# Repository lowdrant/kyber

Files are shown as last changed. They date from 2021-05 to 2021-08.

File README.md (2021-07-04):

# kyber
The toy lightsaber I always wanted as a kid.

## Status
* KyberBoard Rev 1 sent out for fabrication.
* Found Luke Skywalker lightsaber CAD for 3D printing by [CaseStudyno8](https://www.thingiverse.com/thing:1263192/files).
* Circuit design complete and subcircuit interfaces frozen.
* Subcircuits passed breadboard feasibility tests.
* First pass on firmware architecture complete.

## Goals
- Build a lightsaber that extends/retracts, lights up, and makes sound
- Demonstrate "full-stack" electronics engineering skills + some mechanical design
- Stay sane for the rest of the pandemic (everyone needs a hobby)
- Maybe have a Luke Skywalker costume by Halloween 2021?

## [fw](fw/)
Written for the [STM32L051K8T6](hw/KyberBoard/symbol-datasheets/stm32l051t8.pdf) microcontroller. Code should work on any STM32 micrcontroller, and most interfaces are abstracted into header files.

TODO: state diagram

### Configuring STM32CubeIde
Edit project settings to include the multi-project libraries and make the compiler optimize for size. TODO: change saber-libs to holocron-libs
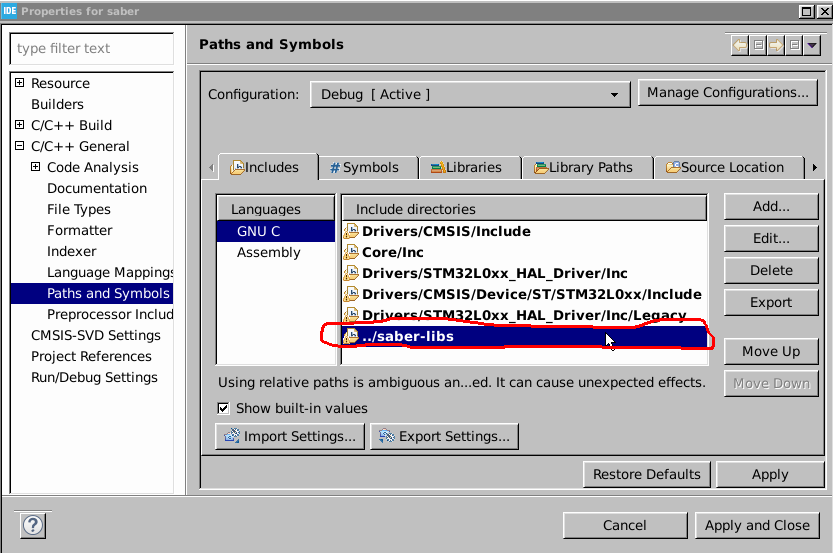
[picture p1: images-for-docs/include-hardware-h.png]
In C/C++ General Settings, add '../saber-libs' to the compiler search path

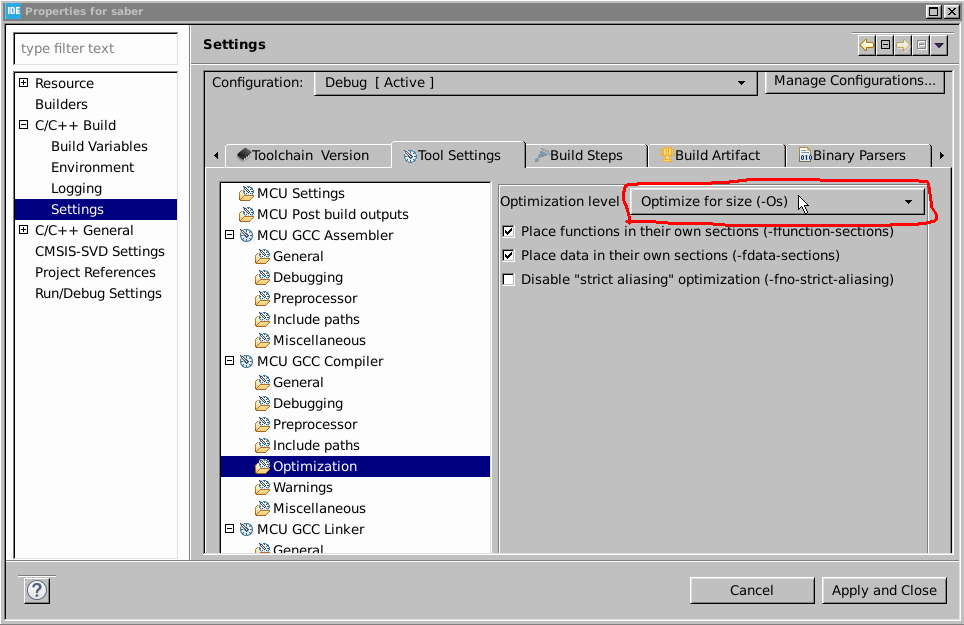
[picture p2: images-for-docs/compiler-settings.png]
Configure the compiler to optimize for size


## [hw](hw/)
A mildly overdesigned PCB to allow flexibility in mechanical design. Designed for test, assembly, and reconfigurability.

### Component Selection Rules
Keep It Simple, Stupid. Stick to driving circuits that have readily available and easily solderable components. If necessary, target components that have in-stock evaluation boards and take the scrap.

### Current (A) Budget
|Component  |Amperage  |Reasoning |
|---|---|---|
|motor |10A |stall current of on-hand dc motor|
|solenoid |1A |12 V/13 Ohms rounded up |
|3V3 bus |1A |typical LDO rating |
|waste |0.5A |safety factor |
|-----------|----------|---------------------------------|
|total |12.5A | |

### Voltage Loss Budget
Mostly concerned with battery protection I<sup>2</sup>R losses. Target < 0.5V peak drop (instinctive spec, not computed)

Major concerns are
- falling below the solenoid turn-on voltage, although I haven't _really_ settled on a solenoid
- throwing off motor control

Current resolution: use ST's [VNHD7008AY eval board example design](reference-manuals/en-vnhd7008ay.pdf). It seems to work fairly well

### Subcircuits
#### Reverse Polarity Protection
Use the built-in protection of the hbridge. Need to characterise I<sup>2</sup>R losses. This will help prevent the Big Dumb<sup>TM</sup> since I plan to use terminal blocks for my main connector.
#### Low-Voltage Shutoff
Grocery store batteries can't drive the actuators, so I'm looking at using a LiPo. This simple Zener-NMOS-PMOS circuit I designed for a student club will should prevent battery over-discharge.
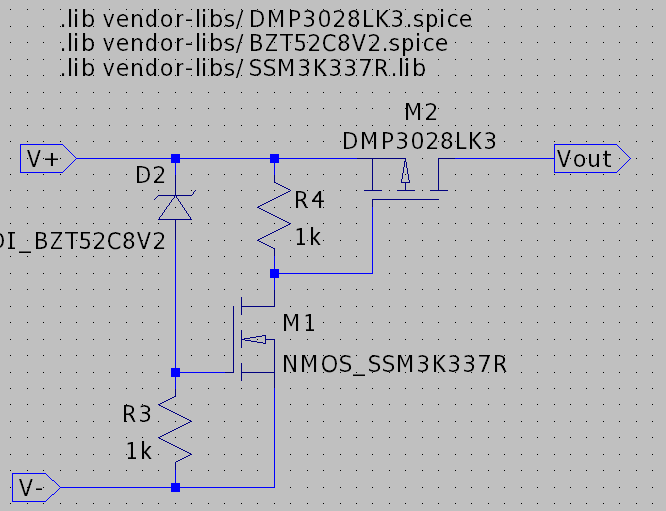
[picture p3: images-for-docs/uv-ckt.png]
UV Protection Circuit

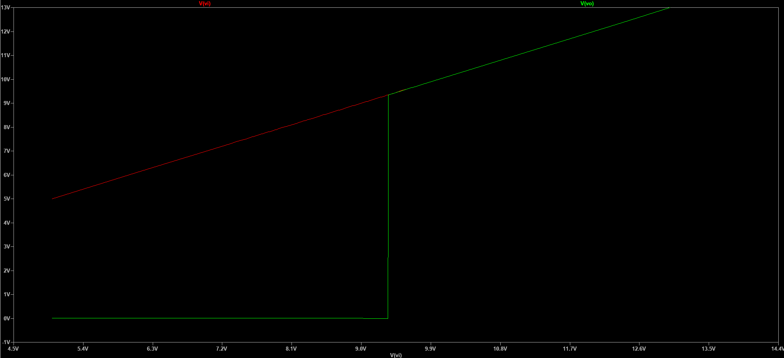
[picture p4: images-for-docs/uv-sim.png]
UV Protection Sim result

When the voltage is above Vthresh, the Zener conducts, so the NMOS conducts, which makes the PMOS conduct.
#### 3V3 Bus
LDO; I do not want to deal with buck converters. I am not being paid for this design.
#### Accelerometer/Gyro
For that sweet, sweet _zwoom_. Use I2C/SPI to make routing a little easier. I have a still-in-stock breakout board for the no-longer-produced [MMA84252QT](https://www.digikey.com/catalog/en/partgroup/mma8452q/11242).
#### Motor Current Sensing
I may use torque control to retract the saber. Currently planning to extend it with a spring, so the "retracted torque" is theoretically better characterized than the "retracted position".
#### HBridge
I found a high-current hbridge IC that does not require complementary PWM (thank you ST). I have limited PWM capabilities due to only low-power ST micros being in stock.
#### Actuators
Low-side switches that do not require inrush-limiting resistors to reduce component count. The [SSM3K337R,LF](https://www.digikey.com/en/products/detail/toshiba-semiconductor-and-storage/SSM3K337R-LF/5056502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) stays well under the maximum drive current and well-preserves a 20kHz square wave.
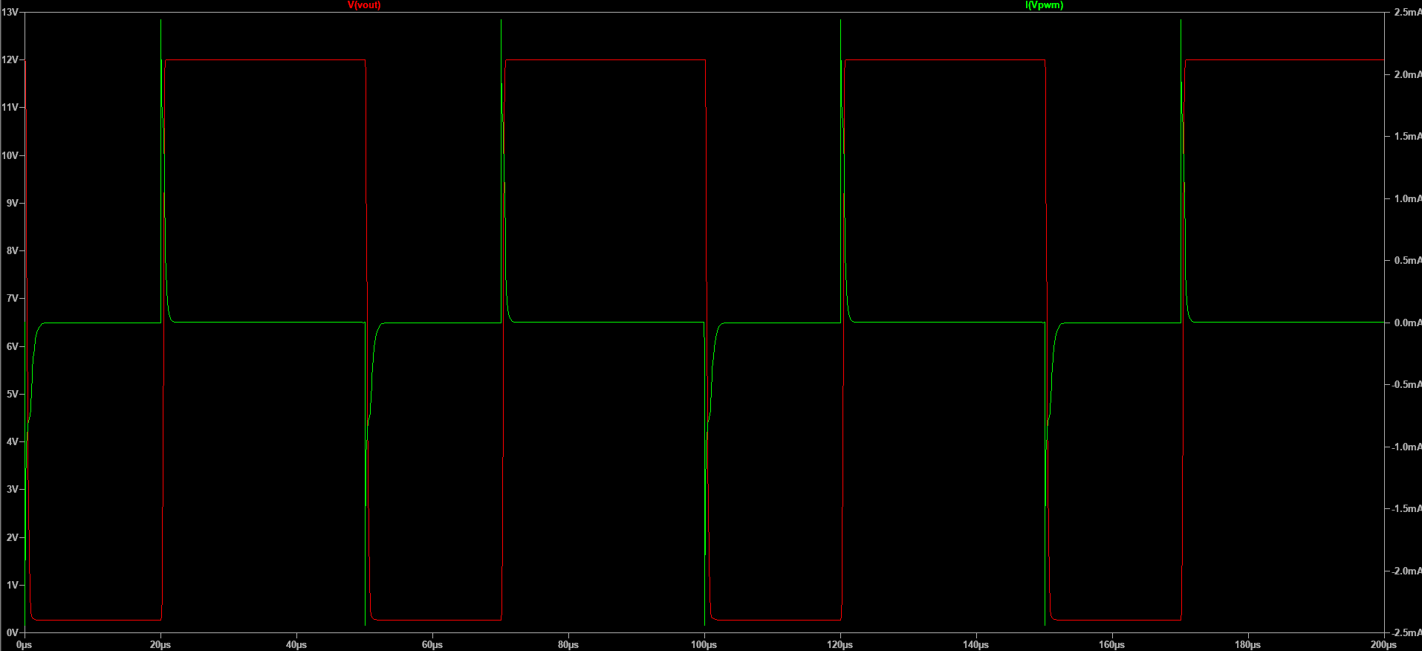
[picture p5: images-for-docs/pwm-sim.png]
PWM Simulation Result


### Non-electrical considerations
- Cost: 4 layers. 2-sided board gives me the needed density, and routing isn't that awful
- I'm not sure I want to hand-solder QFN packages
- Size: Maximize density to maximize mechanical design flexibility.
- Power budget: Meh, I can increase resistances after fab if it's a battery killer

## [cad](cad/)
Found a Luke Skywalker lightsaber CAD for 3D printing by [CaseStudyno8](https://www.thingiverse.com/thing:1263192/files). Was also pointed to Disney's [new lightsaber](https://mashable.com/article/real-lightsaber-star-wars-hotel-disney-world/), which shows some novel mechanical design for retraction. Although I would prefer to be able to fence with my design, the tape measure strategy does show promise.

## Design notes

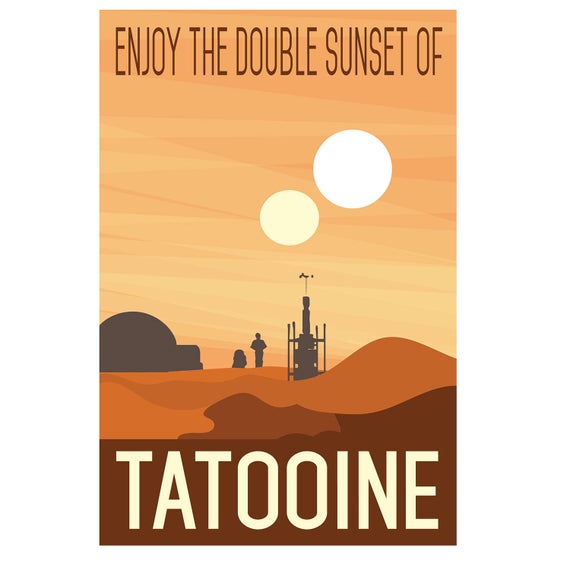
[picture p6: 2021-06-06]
hw/KyberBoard/easter-eggs/tatooine-travel-poster.jpg

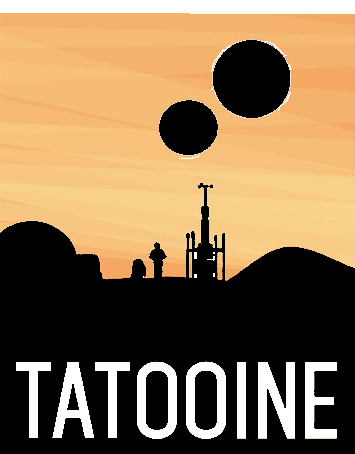
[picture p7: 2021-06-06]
hw/KyberBoard/easter-eggs/tatooine-travel-poster.png

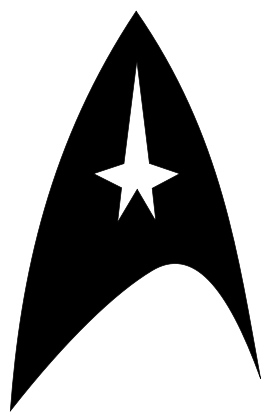
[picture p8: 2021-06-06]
hw/KyberBoard/easter-eggs/starfleet.png

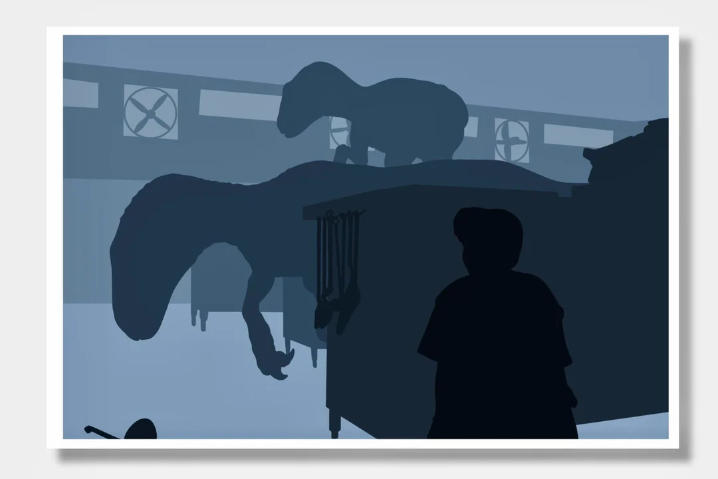
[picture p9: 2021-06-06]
hw/KyberBoard/easter-eggs/velociraptor.webp

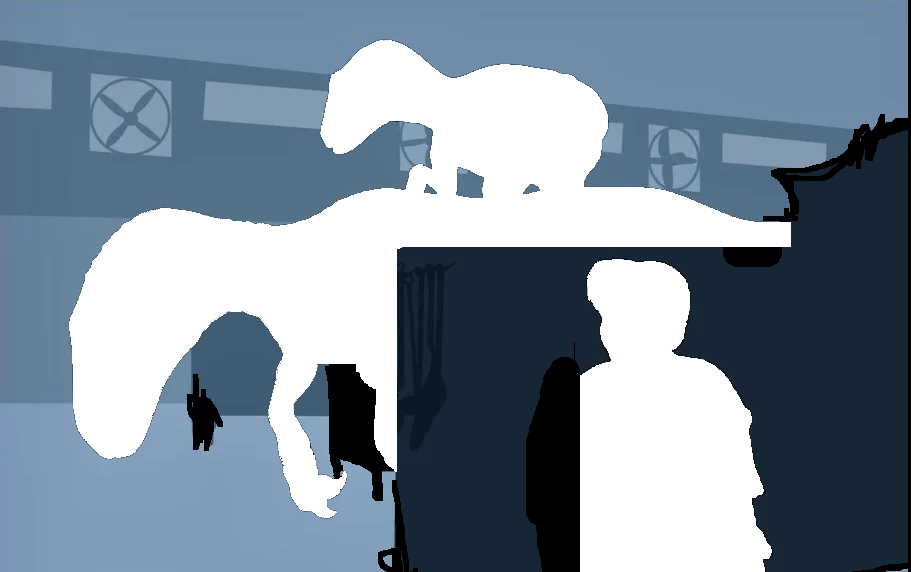
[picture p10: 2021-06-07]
hw/KyberBoard/easter-eggs/velociraptor.png

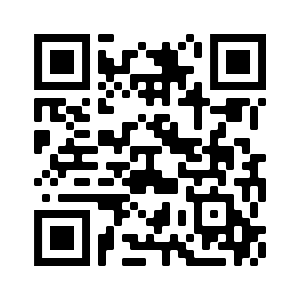
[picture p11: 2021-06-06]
hw/KyberBoard/easter-eggs/qr-funeral-pyre.png

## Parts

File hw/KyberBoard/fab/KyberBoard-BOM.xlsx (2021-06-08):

Id | Designator | Package | Quantity | Designation | Supplier and ref
1 | U4 | MMA8452Q | 1 | MMA8452QT
2 | C15,C2,C4,C5,C7,C8,C17,C18 | C_0603_1608Metric_Pad1.05x0.95mm_HandSolder | 8 | CC0603KRX7R7BB104
7 | Q1 | STL120N4F6AG | 1 | STL120N4F6AG
9 | C6 | CP_Elec_8x10.5 | 1 | UWT1E331MNL1GS
10 | Q4 | STL76DN4LF7AG | 1 | STL76DN4LF7AG
11 | U3 | SOT-223-3_TabPin2 | 1 | AZ1117IH-3.3TRG1
12 | R8,R4,R12,R13,R18 | R_0603_1608Metric_Pad1.05x0.95mm_HandSolder | 5 | CRCW060310K0JNTA
13 | C1 | C_0603_1608Metric_Pad1.05x0.95mm_HandSolder | 1 | CC0603KRX7R7BB333
14 | C3,C12 | C_0603_1608Metric_Pad1.05x0.95mm_HandSolder | 2 | GRM188R61E106KA73D
15 | C9,C11,C10 | C_0603_1608Metric_Pad1.05x0.95mm_HandSolder | 3 | RM188R72A103KA01J
16 | C13 | C_0603_1608Metric_Pad1.05x0.95mm_HandSolder | 1 | GRM188R60J226MEA0J
17 | C16 | C_0603_1608Metric_Pad1.05x0.95mm_HandSolder | 1 | CC0603ZRY5V6BB475
18 | L1 | C_0805_2012Metric | 1 | CIGT201210UHR47MNE
19 | Q3,Q5,Q6,Q7 | SOT-23 | 4 | SSM3K337R
20 | R1,R2,R3,R10,R6,R19,R20 | R_0603_1608Metric_Pad1.05x0.95mm_HandSolder | 7 | CRCW06031K00JNTA
21 | R5 | R_0603_1608Metric_Pad1.05x0.95mm_HandSolder | 1 | CRCW06031K50JNTA
22 | R11,R9 | R_0603_1608Metric_Pad1.05x0.95mm_HandSolder | 2 | CRCW06030000Z0EBC
23 | U2 | ST_PowerSSO-36_SlugDown_ThermalVias | 1 | VNHD7008AYTR
24 | D2 | D_SOD-323_HandSoldering | 1 | BZT52C8V2S-7-F
25 | Q2 | Vishay_PowerPAK_1212-8_Single | 1 | SIS413DN-T1-GE3
26 | 12,3.3,12,3.3 | R_0402_1005Metric | 4 | RC1005J000CS
27 | D4,D5,D6,D7,D8,D9,D12 | D_0603_1608Metric_Pad1.05x0.95mm_HandSolder | 7 | SDM2U30CSP-7
28 |  | TerminalBlock_Phoenix_MPT-0,5-12-2.54_1x12_P2.54mm_Horizontal | 1 | OSTVN12A150
29 | HBT | LED_0603_1608Metric_Pad1.05x0.95mm_HandSolder | 1 | 150060VS75020
30 | UVL | LED_0603_1608Metric_Pad1.05x0.95mm_HandSolder | 1 | 150060RS75020
31 | 12C,3V3 | LED_0603_1608Metric_Pad1.05x0.95mm_HandSolder | 2 | 150060AS75000
33 | , | TerminalBlock_TE_282834-2_1x02_P2.54mm_Horizontal | 2 | 282834-2
34 |  | PinHeader_2x03_P2.54mm_Vertical_SMD | 1 | 15910060
35 |  | SW_SPST_TL3342 | 1 | TL3342F160QG/TR
36 | C19 | C_0603_1608Metric_Pad1.05x0.95mm_HandSolder | 1 | CC0603KRX7R7BB105
37 | U1 | LQFP-32_7x7mm_P0.8mm | 1 | STM32L051K8T6
38 | D13,D14,D15 | D_SOD-523 | 3 | BZT585B3V6T-7

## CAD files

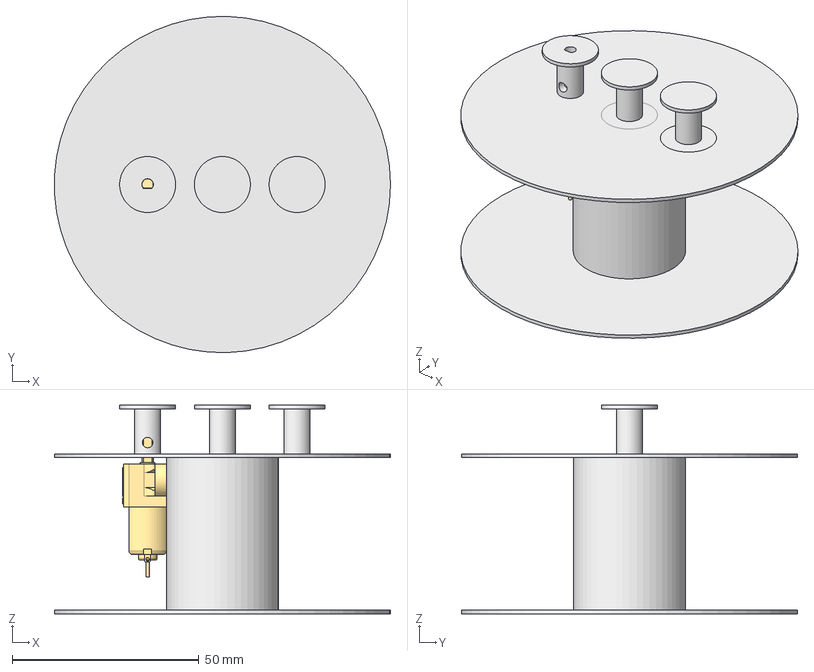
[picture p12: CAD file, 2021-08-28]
cad/innards/assembly.FCStd
89.9 x 90.0 x 55.8 mm
winch-motor
mmgm(extended)_with_bracket
winch-blade1
winch-blade2

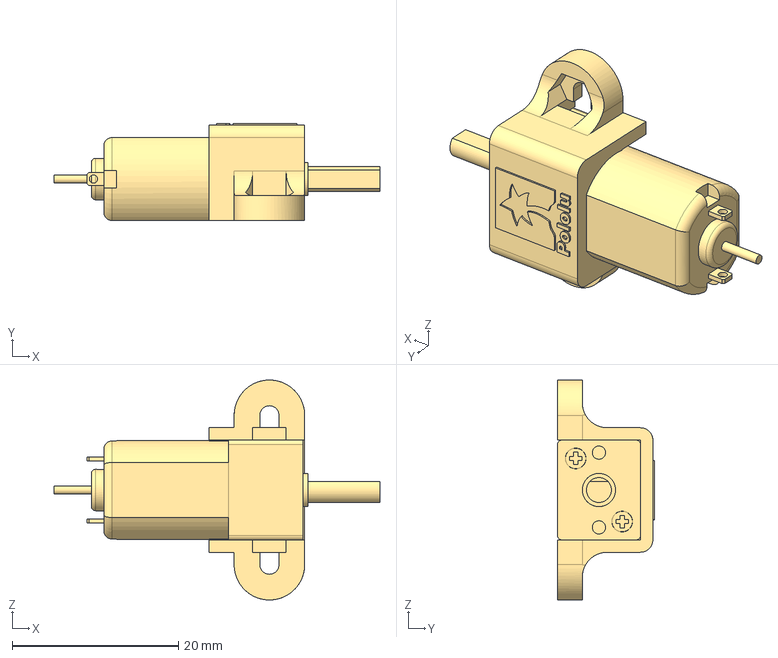
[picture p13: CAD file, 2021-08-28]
cad/innards/motor.FCStd
39.3 x 11.7 x 26.5 mm

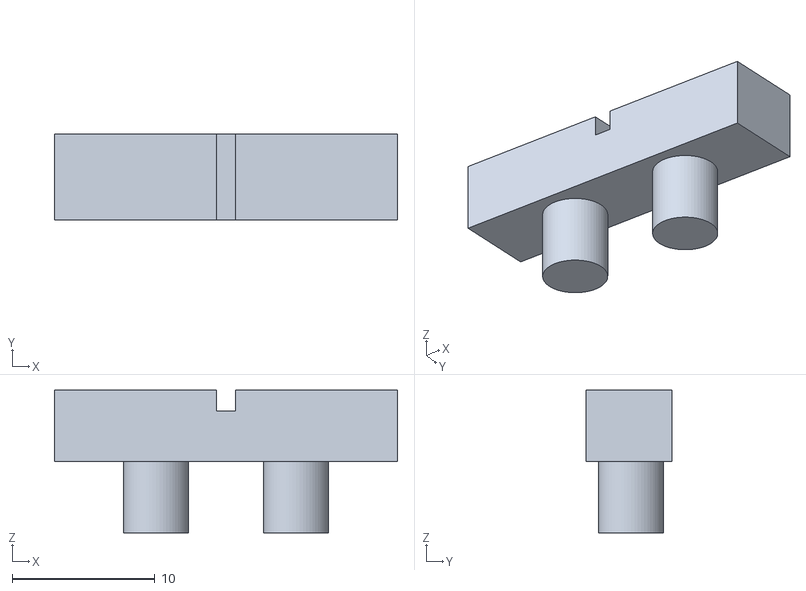
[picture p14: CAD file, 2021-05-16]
cad/saber-base/files/Luke_Skywalker_EP6_-_Power_Regulator.STL
24.0 x 6.00 x 10.0

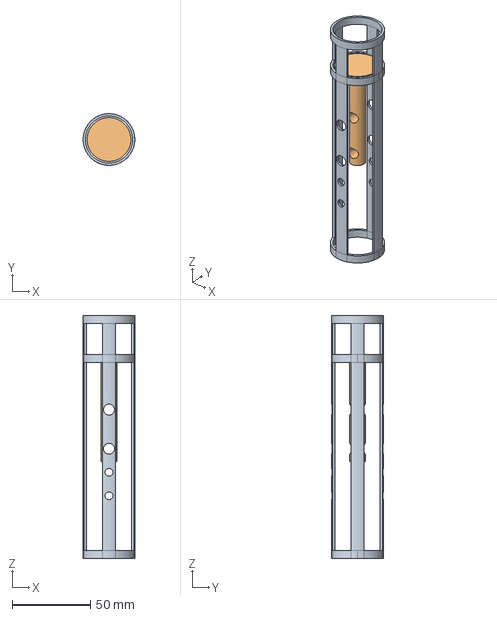
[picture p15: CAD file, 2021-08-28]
cad/test_rig.FCStd
33.0 x 33.0 x 155.0 mm
chassis
shaper

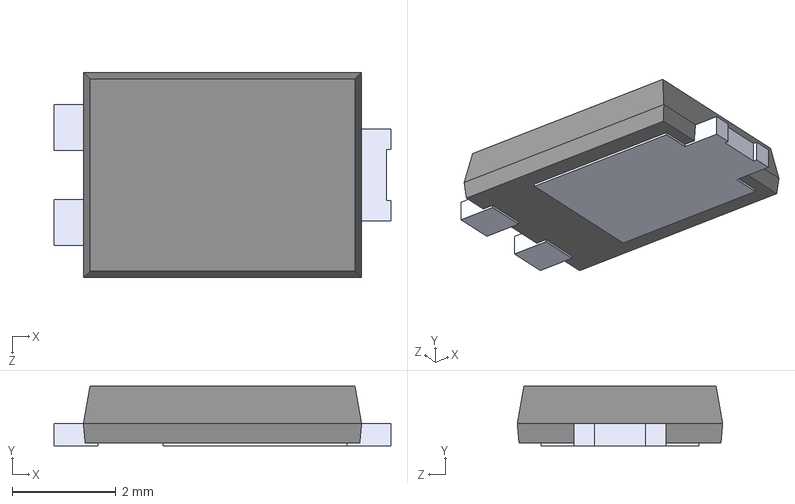
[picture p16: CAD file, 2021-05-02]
hw/KyberBoard/footprints/powerdi5/D_PowerDI5-AAK.step
6.50 x 1.15 x 3.97 mm

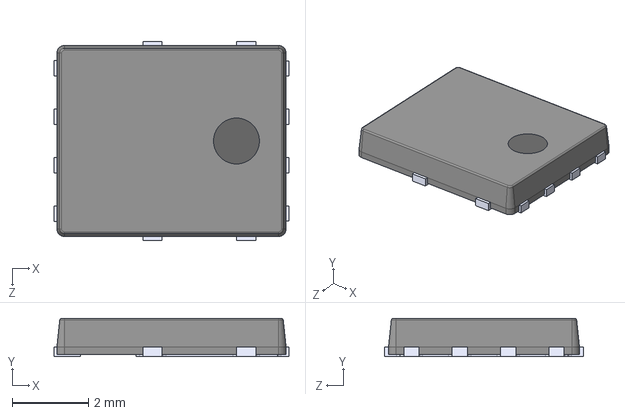
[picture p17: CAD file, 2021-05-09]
hw/KyberBoard/footprints/STL120N4F6AG/STL120N4F6AG.step
6.15 x 1.00 x 5.20 mm

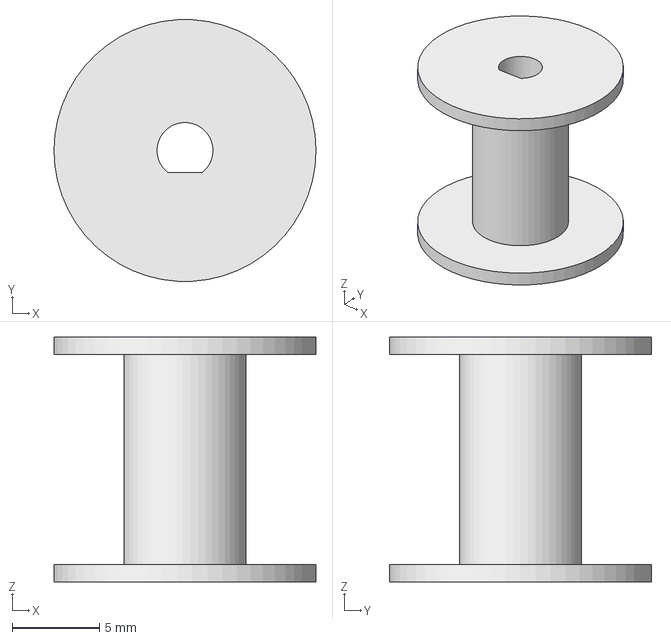
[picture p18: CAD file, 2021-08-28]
cad/innards/winch.FCStd
15.0 x 15.0 x 14.0 mm

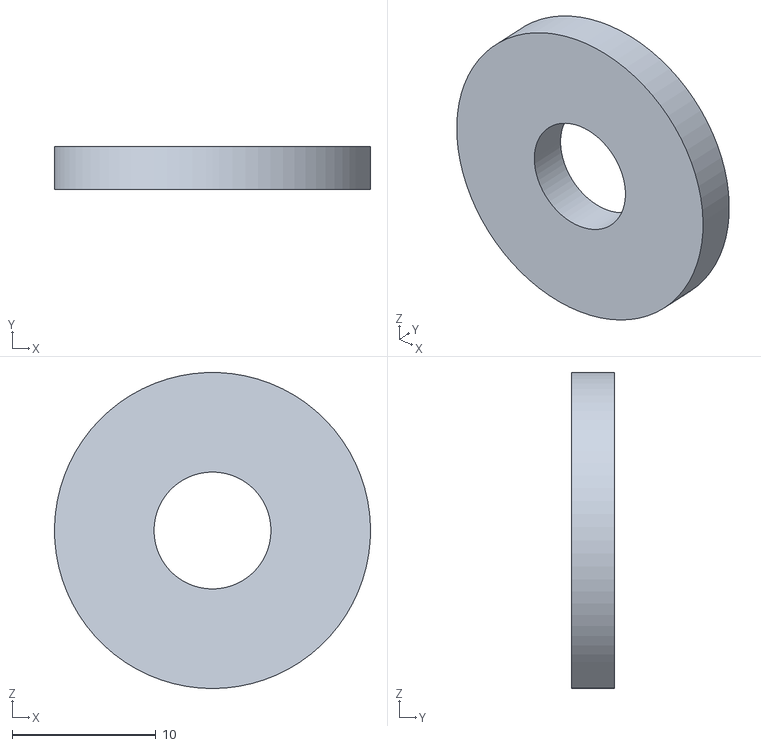
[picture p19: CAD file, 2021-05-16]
cad/saber-base/files/Luke_Skywalker_EP6_-_Lower_Disc.STL
22.0 x 3.00 x 22.0

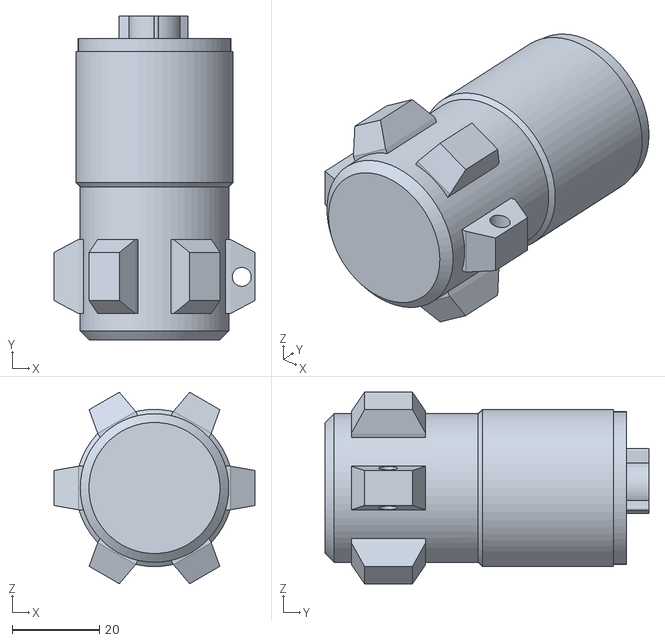
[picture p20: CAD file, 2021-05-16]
cad/saber-base/files/EP6_Luke_Pommel_Solid.STL
46.0 x 74.1 x 43.8

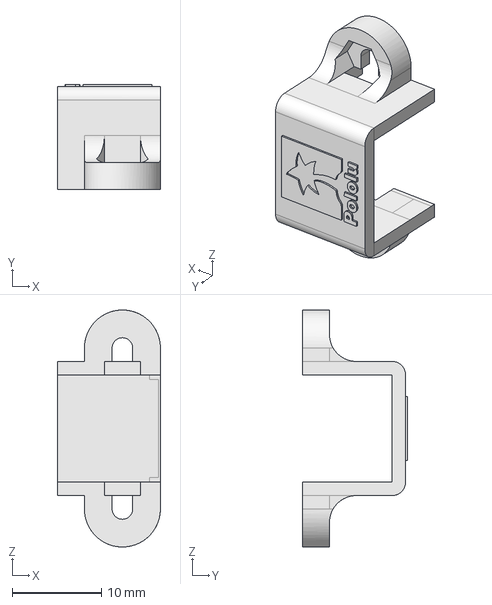
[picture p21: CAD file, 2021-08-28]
cad/innards/MTRBRACKTEST.FCStd
11.5 x 11.7 x 26.5 mm

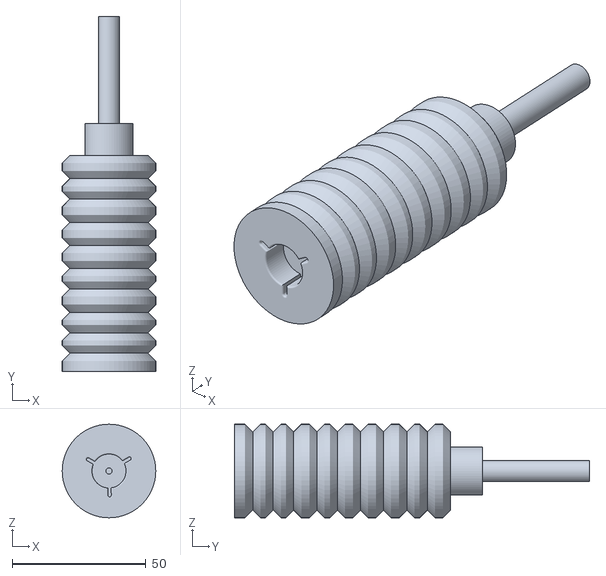
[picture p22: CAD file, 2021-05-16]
cad/saber-base/files/EP6_Luke_Grip_Solid.STL
35.0 x 132.7 x 35.0

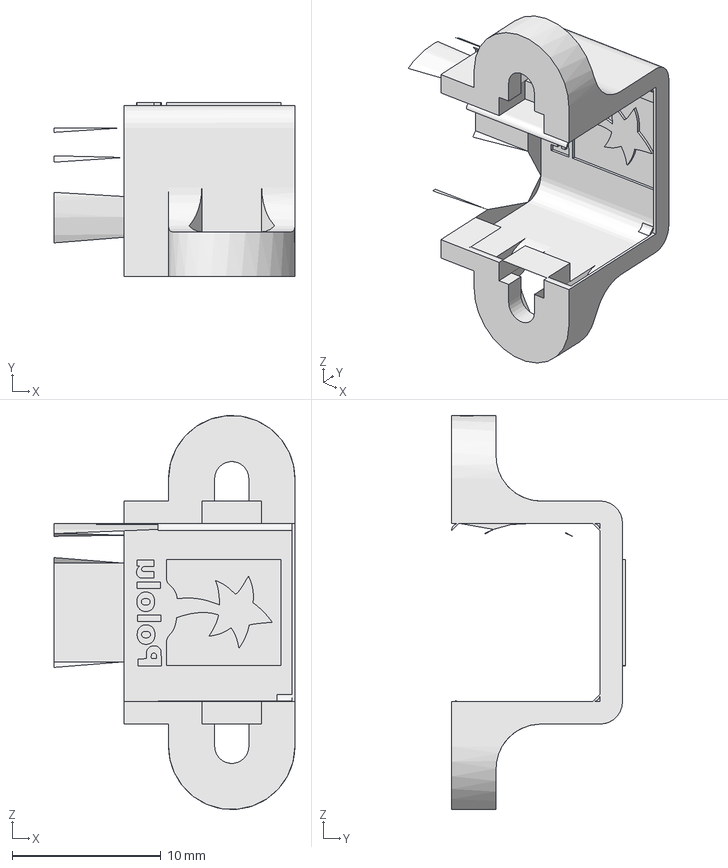
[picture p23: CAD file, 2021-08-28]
cad/innards/motor-bracket.FCStd
16.2 x 11.7 x 26.5 mm

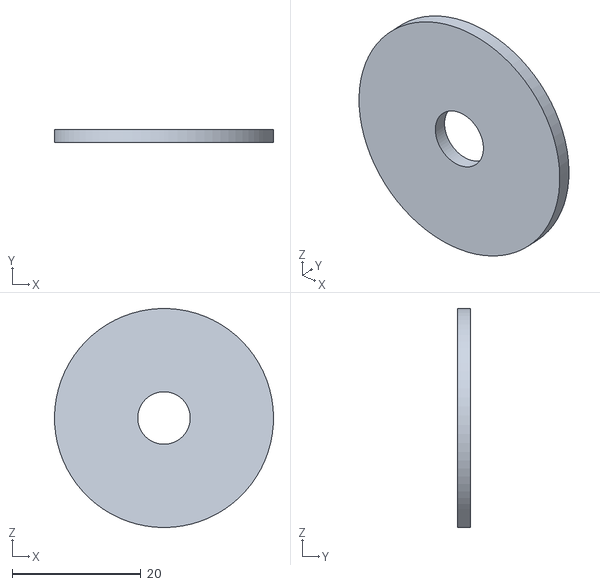
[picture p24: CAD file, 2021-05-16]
cad/saber-base/files/Luke_Skywalker_EP6_-_Upper_Disc.STL
34.0 x 2.00 x 34.0

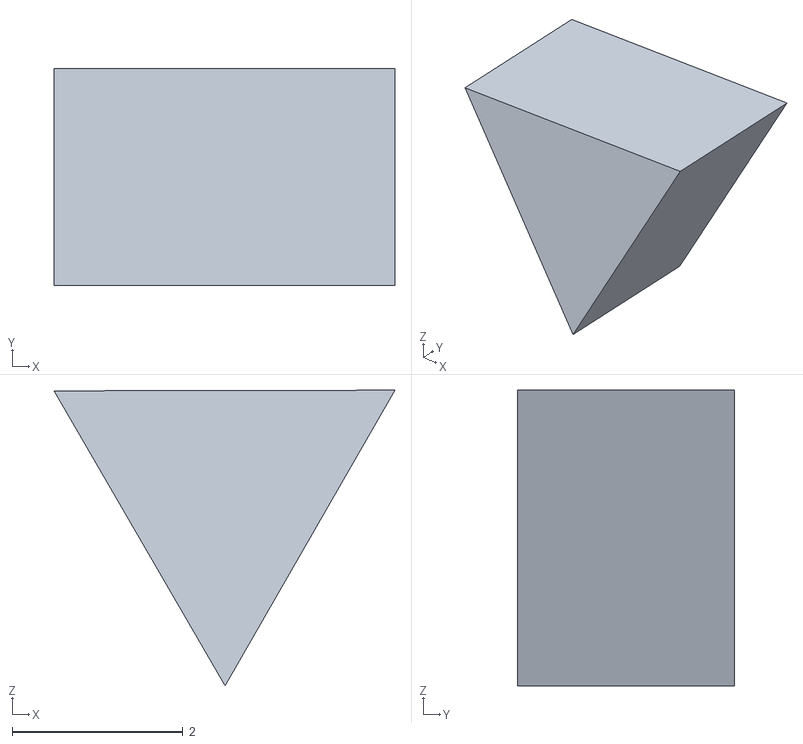
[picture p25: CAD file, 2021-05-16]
cad/saber-base/files/Luke_Skywalker_EP6_-Triangular__Indicator.STL
4.00 x 2.54 x 3.47

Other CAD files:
cad/saber-base/files/Luke_Skywalker_EP6_-_Upper_Copper_Coupling.STL
cad/saber-base/files/EP6_Luke_Midsection_Solid.STL
cad/saber-base/files/Luke_Skywalker_EP6_-_Belt_Ring.STL
cad/saber-base/files/Luke_Skywalker_EP6_-_Emitter_Nipple.STL
cad/saber-base/files/Luke_Skywalker_EP6_-_Grip.STL
cad/saber-base/files/Luke_Skywalker_EP6_-_Luke_Emitter.STL
cad/saber-base/files/Luke_Skywalker_EP6_-_Midsection.STL
cad/saber-base/files/Luke_Skywalker_EP6_-_Pommel.STL
cad/saber-base/files/Luke_Skywalker_EP6_-_Switch.STL
cad/saber-base/files/Luke_Skywalker_EP6_-_Switch_Casing.STL
cad/saber-base/files/Luke_Skywalker_EP6_-__Switch_Lower.STL

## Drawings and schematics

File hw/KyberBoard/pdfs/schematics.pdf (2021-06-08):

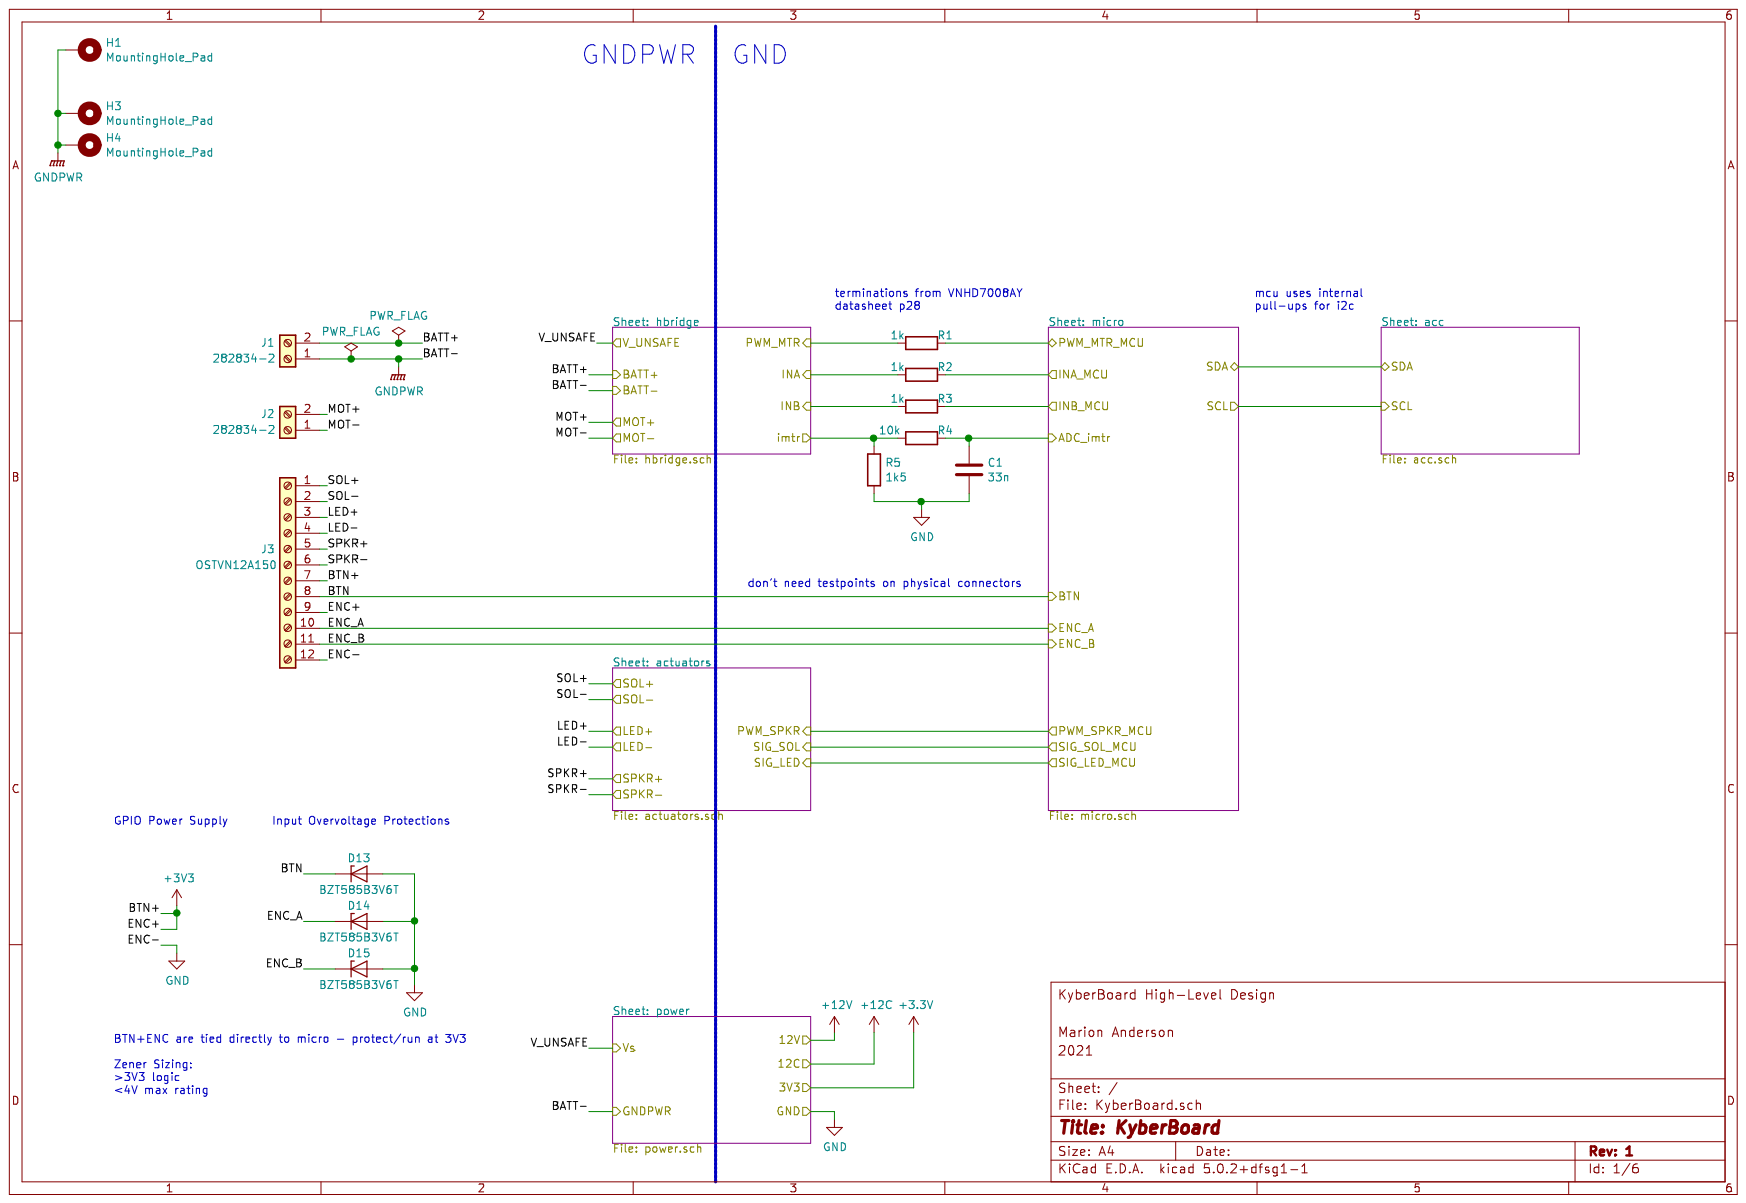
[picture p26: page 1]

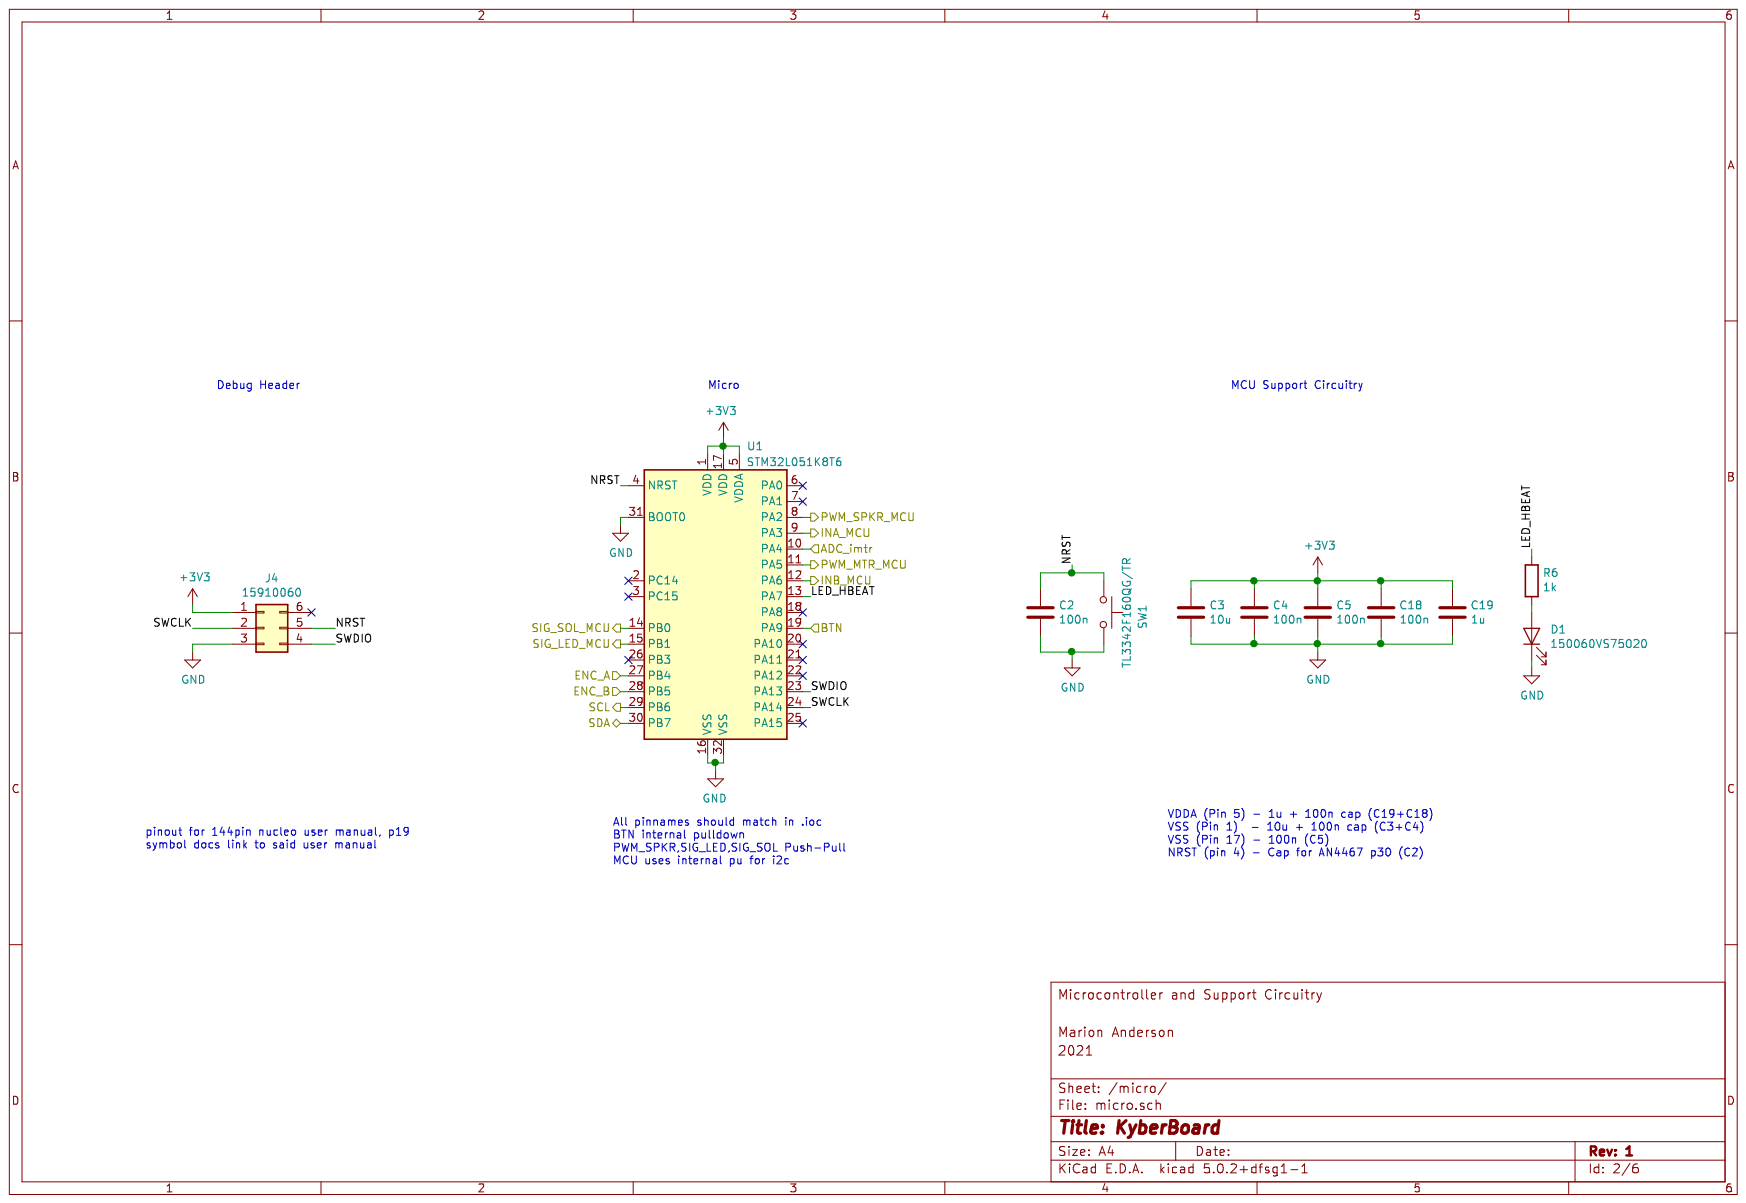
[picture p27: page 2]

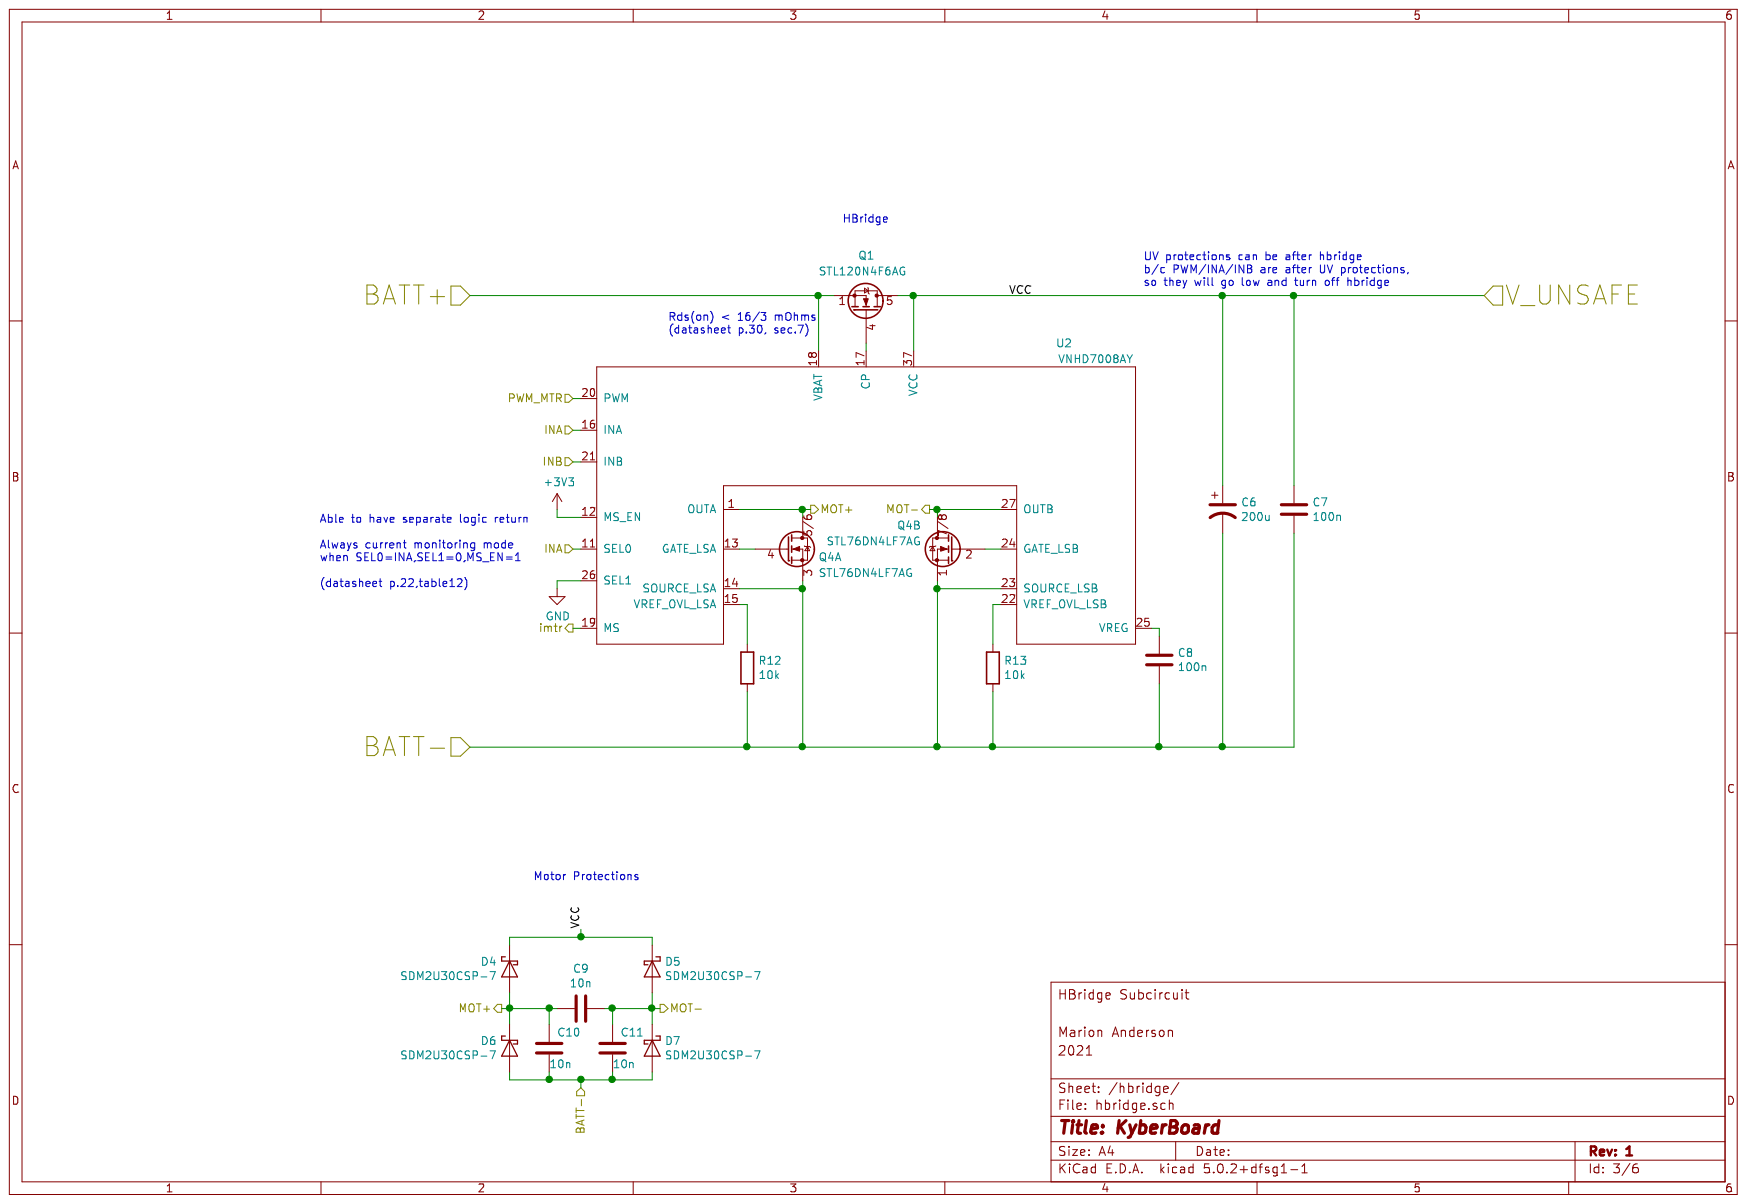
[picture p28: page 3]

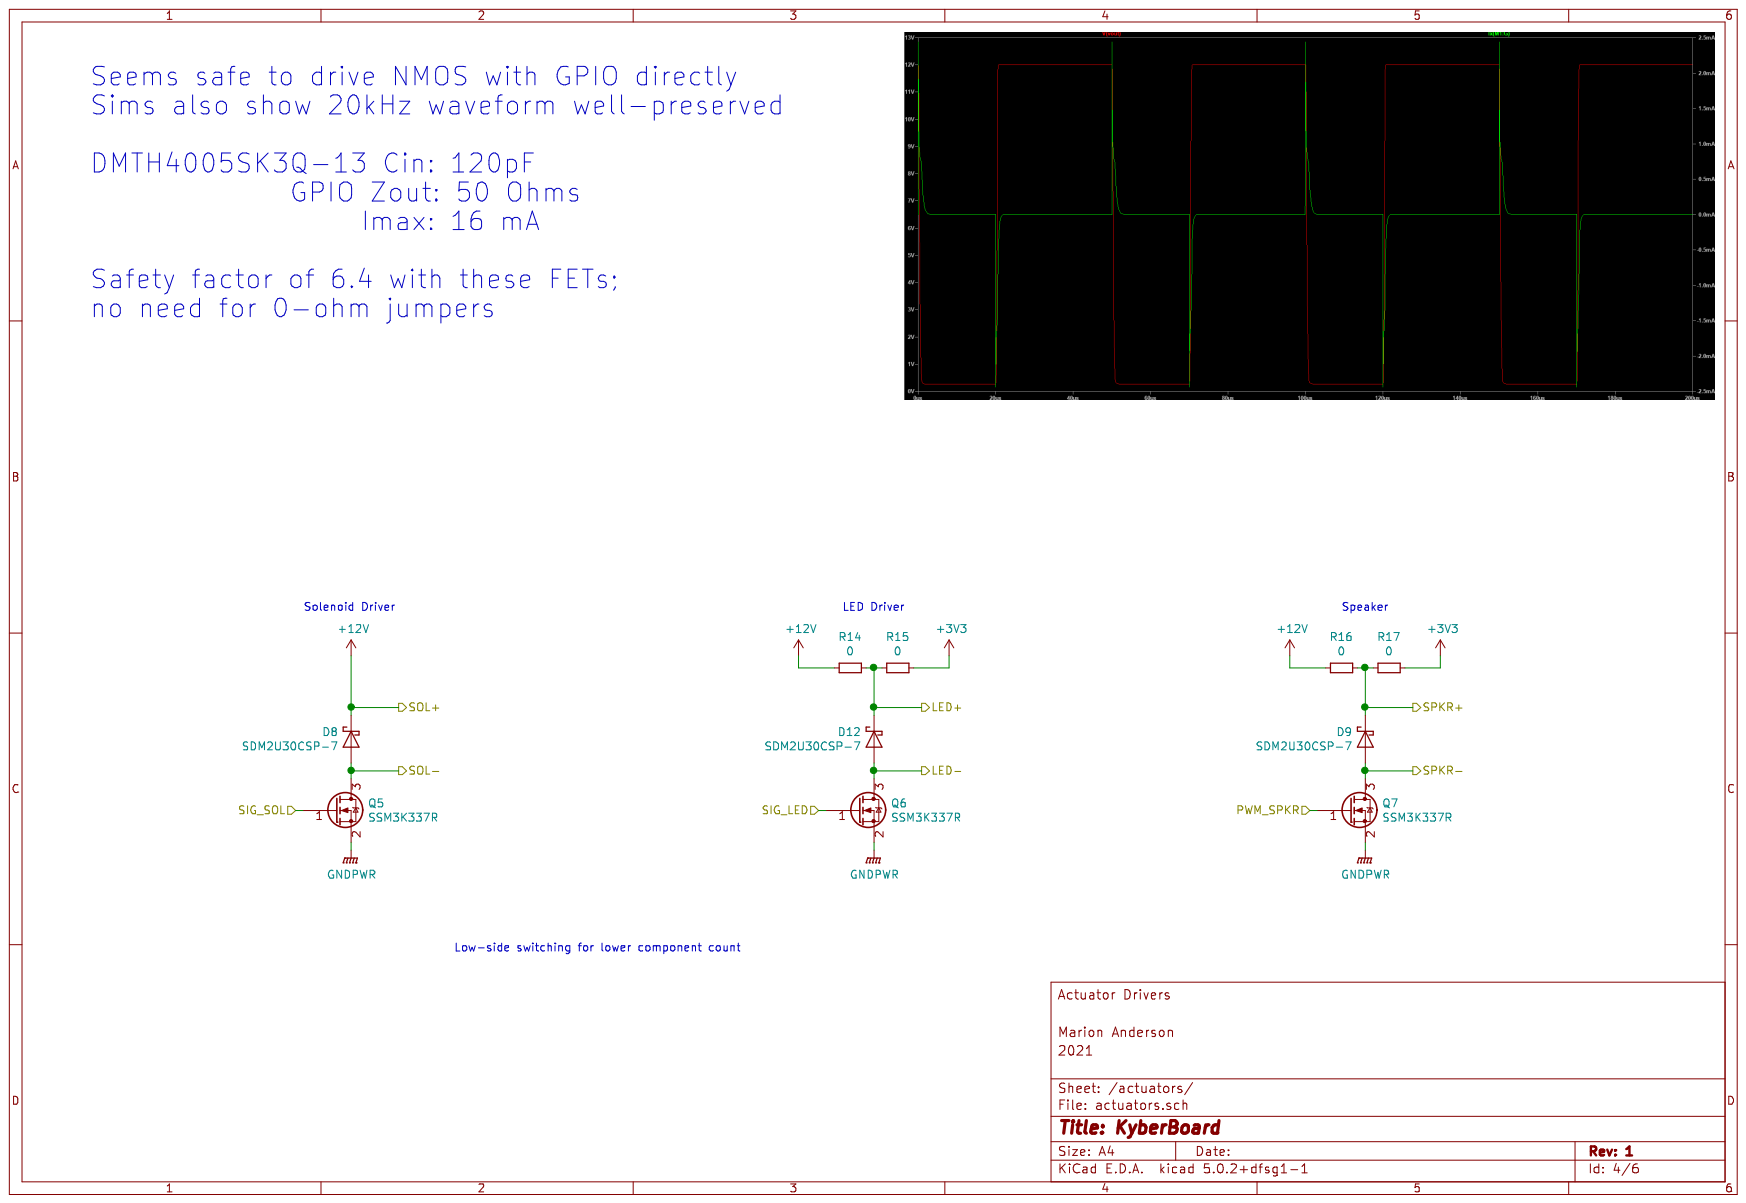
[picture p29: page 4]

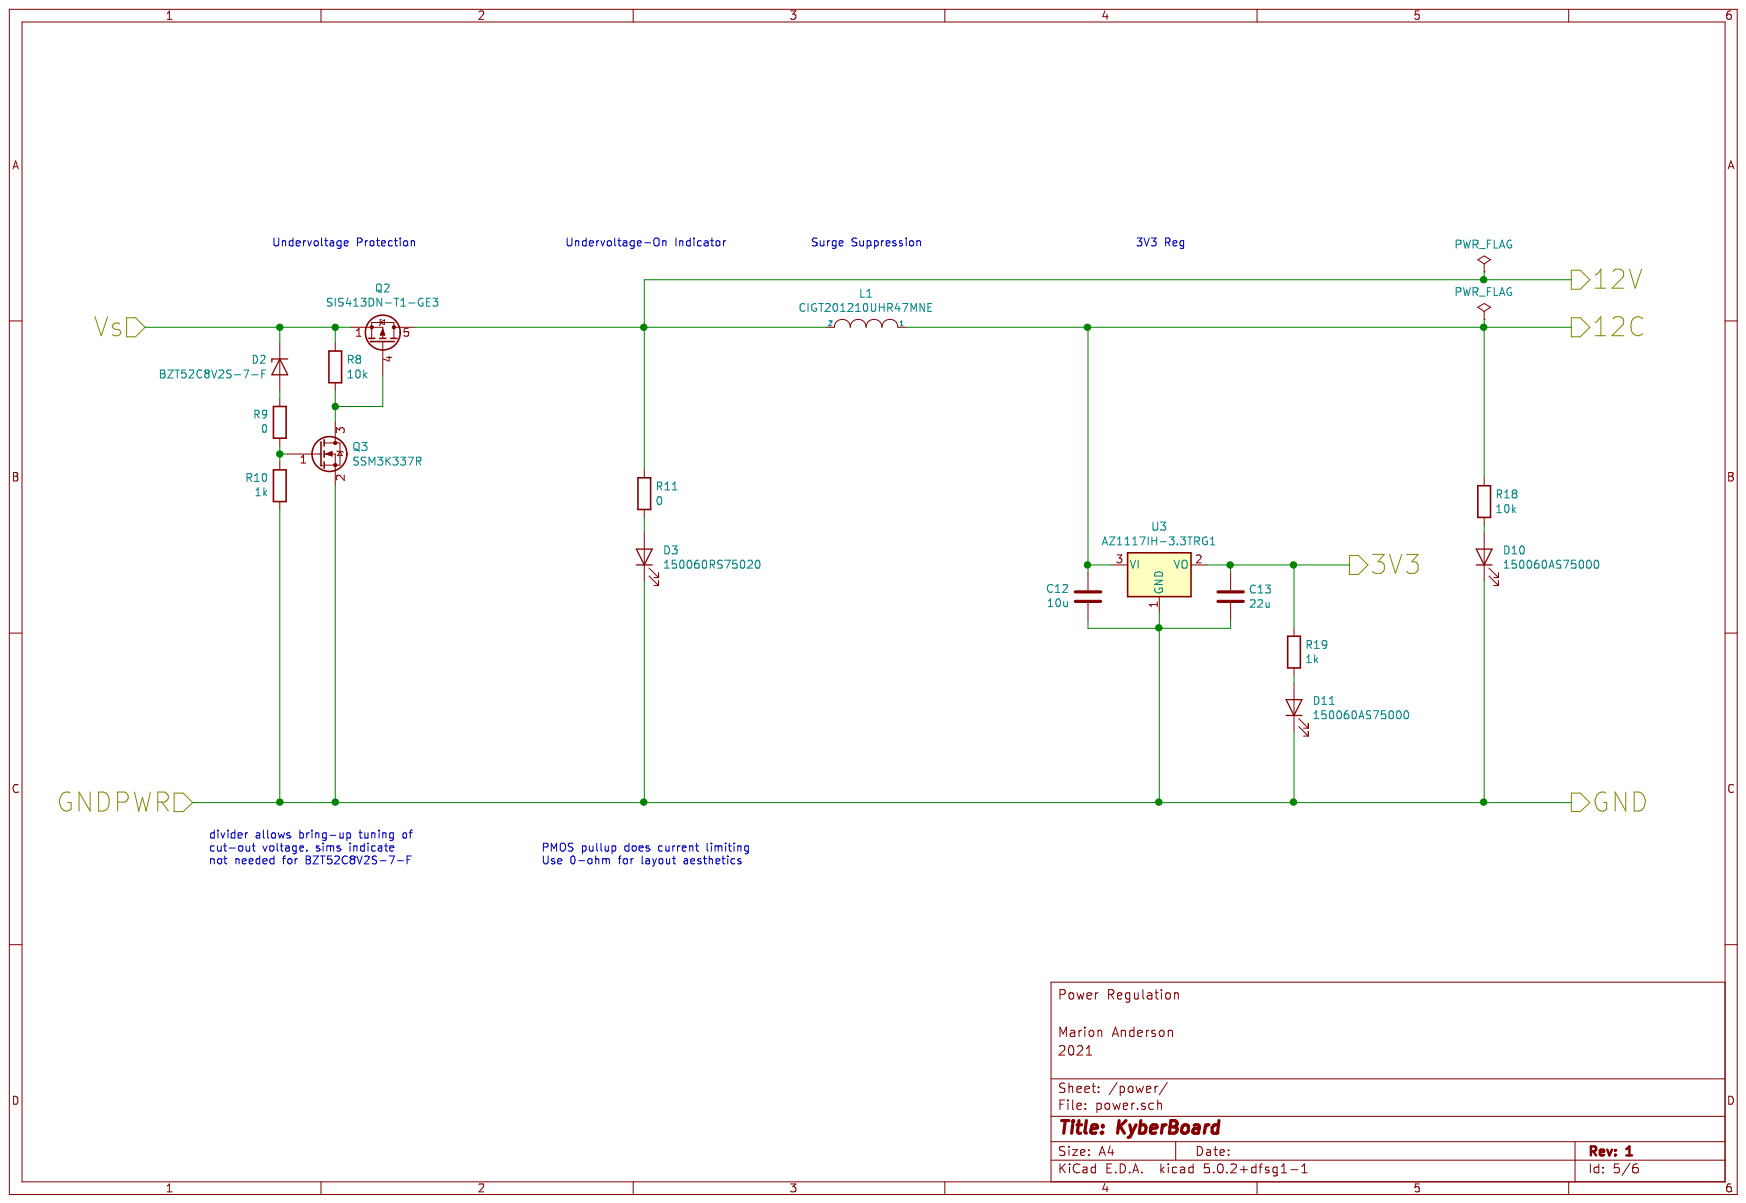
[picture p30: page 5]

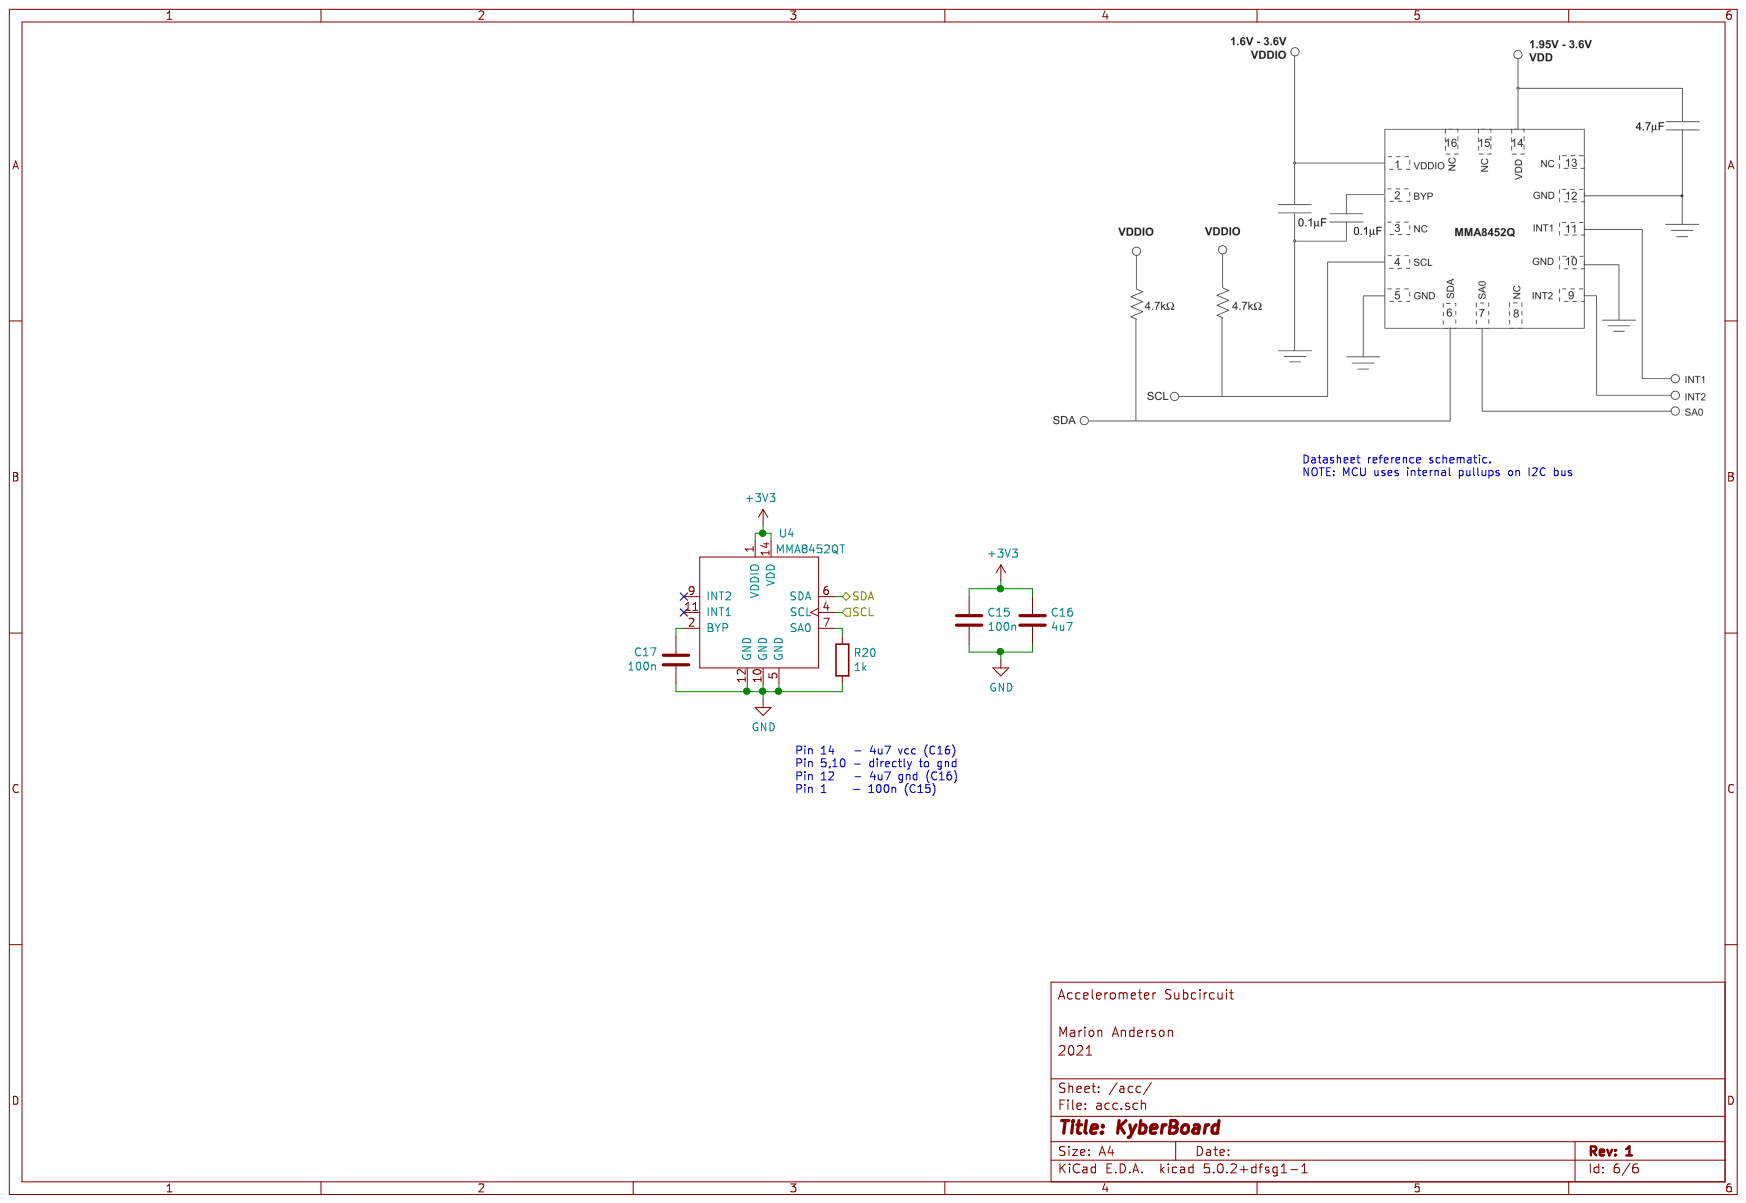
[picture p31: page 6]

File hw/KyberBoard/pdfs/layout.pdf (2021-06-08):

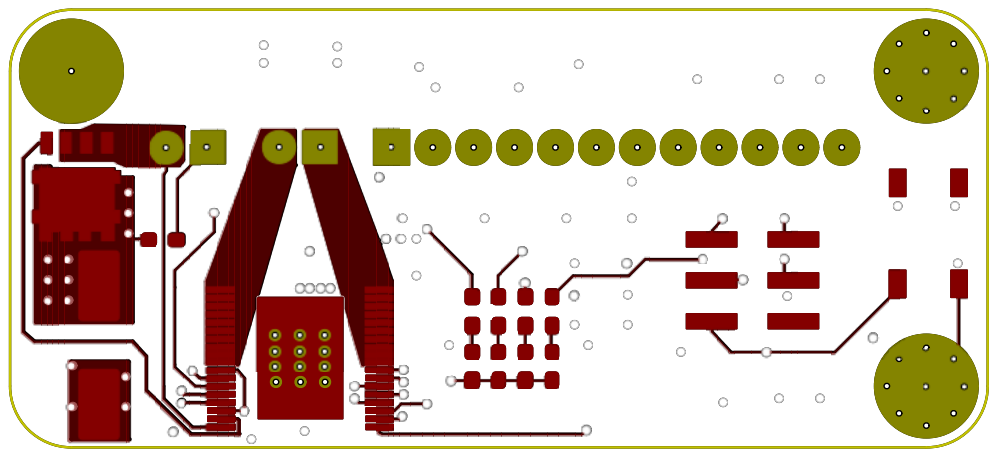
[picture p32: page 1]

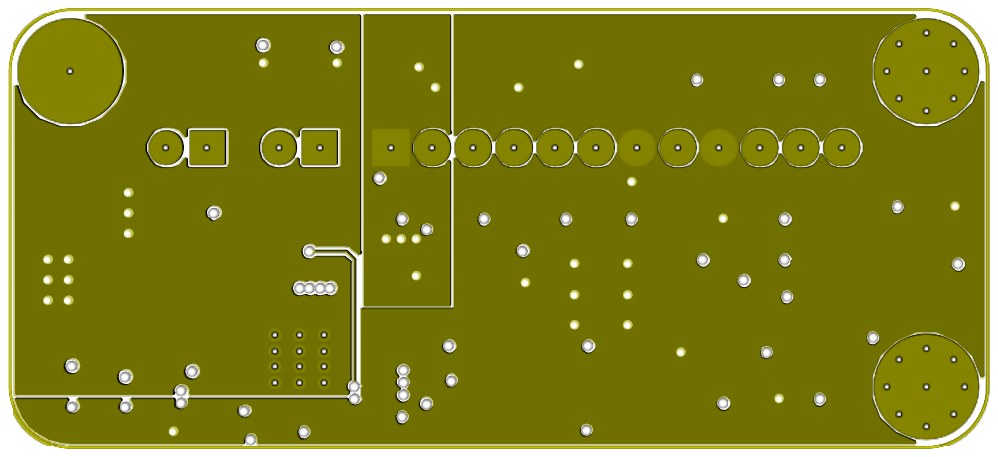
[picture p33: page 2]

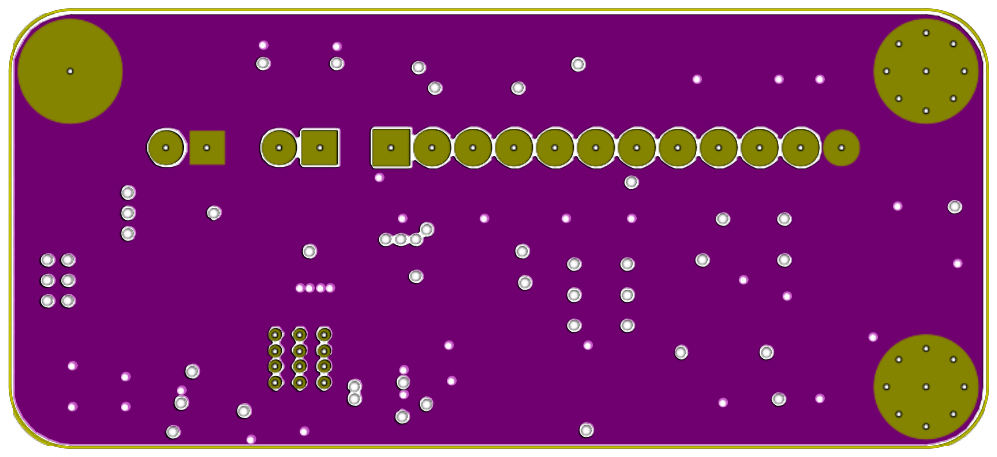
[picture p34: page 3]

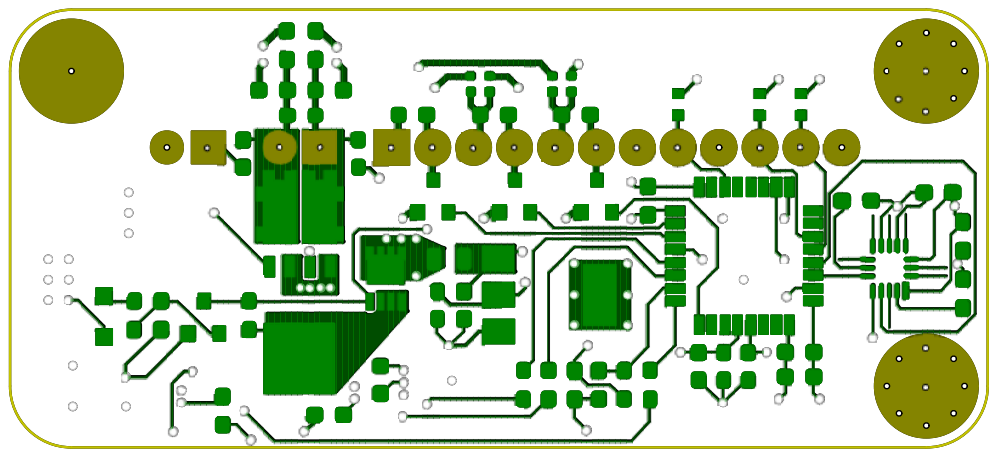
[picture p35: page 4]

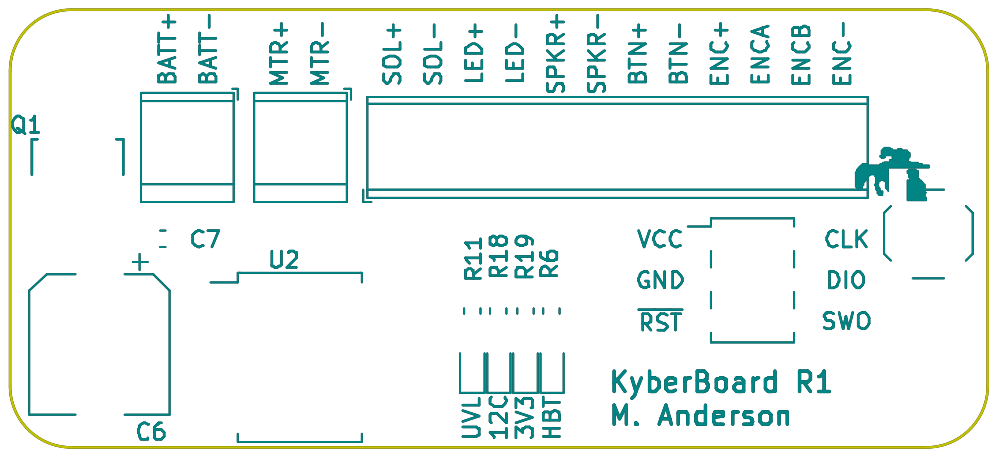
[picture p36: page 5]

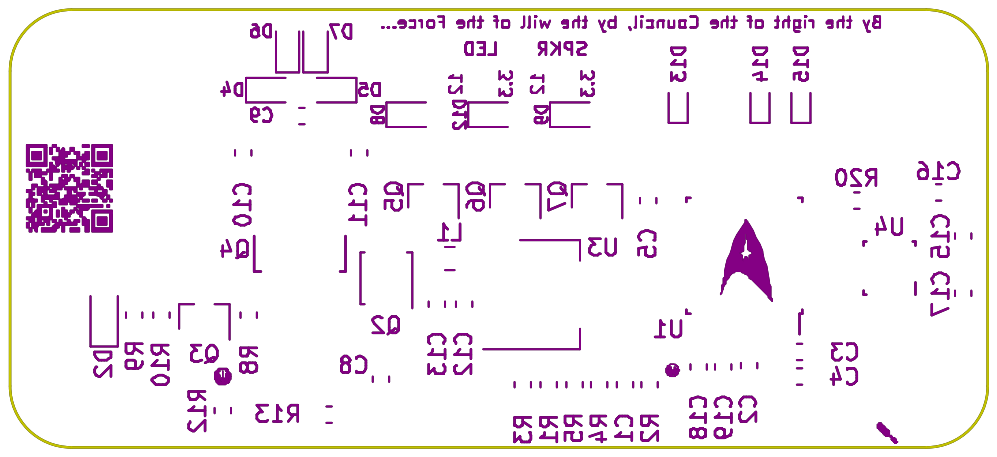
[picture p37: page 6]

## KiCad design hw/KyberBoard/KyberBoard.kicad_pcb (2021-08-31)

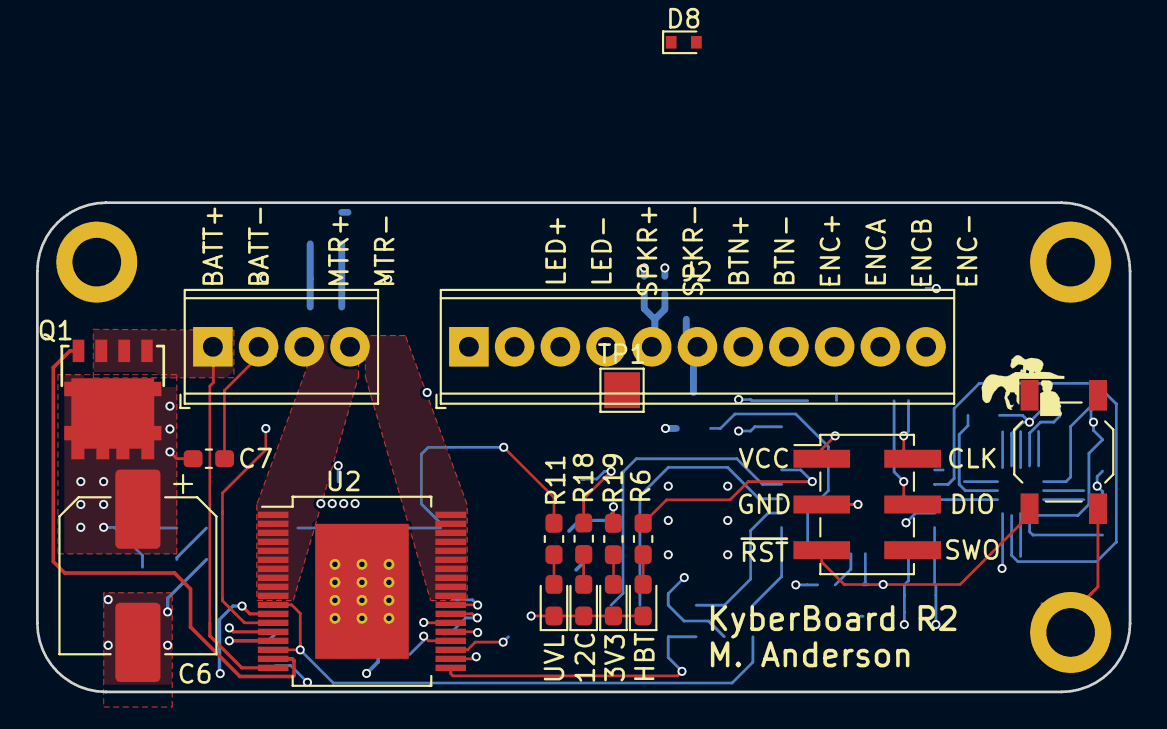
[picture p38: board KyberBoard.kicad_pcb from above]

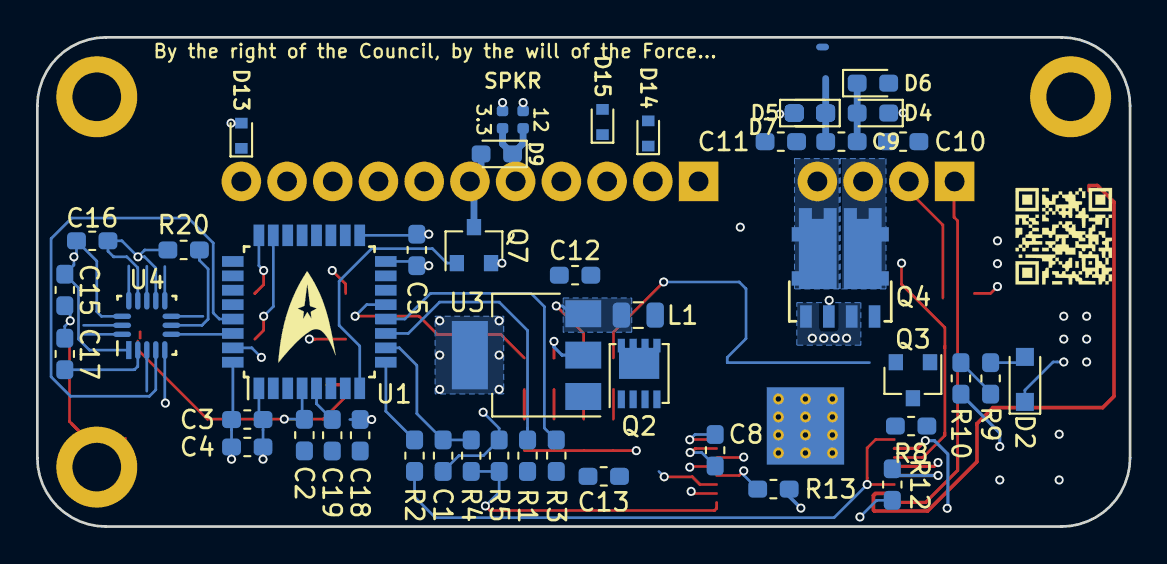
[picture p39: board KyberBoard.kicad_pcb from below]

Board: 4 copper layers, 60.7 x 27.2 mm, 67 parts (46 on the bottom side), 44 nets.

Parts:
C1: 33n; C_0603_1608Metric_Pad1.05x0.95mm_HandSolder
C2, C4, C5, C7, C8, C15, C17, C18: 100n; C_0603_1608Metric_Pad1.05x0.95mm_HandSolder
C3, C12: 10u; C_0603_1608Metric_Pad1.05x0.95mm_HandSolder
C6: 200u; CP_Elec_8x10.5
C9, C10, C11: 10n; C_0603_1608Metric_Pad1.05x0.95mm_HandSolder
C13: 22u; C_0603_1608Metric_Pad1.05x0.95mm_HandSolder
C16: 4u7; C_0603_1608Metric_Pad1.05x0.95mm_HandSolder
C19: 1u; C_0603_1608Metric_Pad1.05x0.95mm_HandSolder
D1: 150060VS75020; LED_0603_1608Metric_Pad1.05x0.95mm_HandSolder
D2: BZT52C8V2S-7-F; D_SOD-323_HandSoldering
D3: 150060RS75020; LED_0603_1608Metric_Pad1.05x0.95mm_HandSolder
D4, D5, D6, D7, D9: SDM2U30CSP-7; D_0603_1608Metric_Pad1.05x0.95mm_HandSolder
D8, D13, D14, D15: BZT585B3V6T; D_SOD-523
D10, D11: 150060AS75000; LED_0603_1608Metric_Pad1.05x0.95mm_HandSolder
H1, H3, H4: MountingHole_Pad; MountingHole_2.7mm_M2.5_ISO7380_Pad
J1: Screw_Terminal_01x04; TerminalBlock_Phoenix_MPT-0,5-4-2.54_1x04_P2.54mm_Horizontal
J2: Screw_Terminal_01x11; TerminalBlock_Phoenix_MPT-0,5-11-2.54_1x11_P2.54mm_Horizont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
J4: 15910060; PinHeader_2x03_P2.54mm_Vertical_SMD
L1: CIGT201210UHR47MNE; C_0805_2012Metric
Q1: STL120N4F6AG
Q2: SIS413DN-T1-GE3; Vishay_PowerPAK_1212-8_Single
Q3: SSM3K337R; SOT-23
Q4: STL76DN4LF7AG
Q7: SSM3K337R,LF; SOT-23
R1, R2, R3, R6, R8, R10, R19, R20: 1k; R_0603_1608Metric_Pad1.05x0.95mm_HandSolder
R4, R11, R12, R13, R18: 10k; R_0603_1608Metric_Pad1.05x0.95mm_HandSolder
R5: 1k5; R_0603_1608Metric_Pad1.05x0.95mm_HandSolder
R9: 0; R_0603_1608Metric_Pad1.05x0.95mm_HandSolder
R16, R17: 0; R_0402_1005Metric
SW1: TL3342F160QG/TR; SW_SPST_TL3342
TP1: TestPoint; TestPoint_Pad_2.0x2.0mm
U1: STM32L051K8T6; LQFP-32_7x7mm_P0.8mm
U2: VNHD7008AY; ST_PowerSSO-36_SlugDown_ThermalVias
U3: AZ1117IH-3.3TRG1; SOT-223-3_TabPin2
U4: MMA8452QT; MMA8452Q

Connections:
+3V3: C3.1, C4.1, C5.1, C13.1, C15.2, C16.2, C18.1, C19.1, J2.1, J2.7, J2.10, J4.1, R17.1, R19.1, U1.1, U1.5, U1.17, U2.12, U3.2, U4.1, U4.14
+12C: C12.2, L1.1, R18.1, U3.3
+12V: L1.2, Q2.5, R16.2
/BATT+: J1.1, Q1.1, Q1.2, Q1.3, U2.18
/BTN: D13.1, J2.11, U1.19
/ENC_A: D14.1, J2.2, U1.28
/ENC_B: D15.1, J2.3, U1.27
/LED_TX: D8.1, J2.8
/MOT+: C9.2, C10.1, D4.2, D6.1, J1.3, Q4.5/6, U2.1, U2.2, U2.3, U2.4, U2.5, U2.6, U2.7, U2.8, U2.9, U2.10
/MOT-: C9.1, C11.1, D5.2, D7.1, J1.4, Q4.7/8, U2.27, U2.28, U2.29, U2.30, U2.31, U2.32, U2.33, U2.34, U2.35, U2.36
/SPKR+: D9.1, J2.5, R16.1, R17.2
/SPKR-: D9.2, J2.6, Q7.3
/V_UNSAFE: C6.1, C7.1, D2.1, D4.1, D5.1, Q1.5, Q2.1, Q2.2, Q2.3, R8.1, U2.37
/acc/SCL: U1.29, U4.4
/acc/SDA: U1.30, U4.6
/actuators/PWM_SPKR: Q7.1, TP1.1, U1.8
/hbridge/INA: R2.2, U2.11, U2.16
/hbridge/INB: R3.2, U2.21
/hbridge/PWM_MTR: R1.2, U2.20
/hbridge/imtr: R4.2, R5.1, U2.19
/micro/ADC_imtr: C1.1, R4.1, U1.10
/micro/INA_MCU: R2.1, U1.9
/micro/INB_MCU: R3.1, U1.12
/micro/LED_HBEAT: R6.2, U1.13
/micro/NRST: C2.1, J4.5, SW1.1, U1.4
/micro/PWM_MTR_MCU: R1.1, U1.11
/micro/SWCLK: J4.2, U1.24
/micro/SWDIO: J4.4, U1.23
GND: C1.2, C2.2, C3.2, C4.2, C5.2, C6.2, C7.2, C8.2, C10.2, C11.2, C12.1, C13.2, C15.1, C16.1, C17.1, C18.2, C19.2, D1.1, D3.1, D6.2, D7.2, D8.2, D10.1, D11.1, D13.2, D14.2, D15.2, H1.1, H3.1, H4.1, J1.2, J2.4, J2.9, J4.3, Q3.2, Q4.1, Q4.3, Q7.2, R5.2, R10.1, R12.2, R13.2, R20.2, SW1.2, U1.16, U1.31, U1.32, U2.14, U2.23, U2.26, U3.1, U4.5, U4.10, U4.12
unnamed: C8.1, U2.25
unnamed: C17.2, U4.2
unnamed: D1.2, R6.1
unnamed: D2.2, R9.2
unnamed: D3.2, R11.2
unnamed: D10.2, R18.2
unnamed: D11.2, R19.2
unnamed: Q1.4, U2.17
unnamed: Q2.4, Q3.3, R8.2, R11.1
unnamed: Q3.1, R9.1, R10.2
unnamed: Q4.2, U2.24
unnamed: Q4.4, U2.13
unnamed: R12.1, U2.15
unnamed: R13.1, U2.22
unnamed: R20.1, U4.7

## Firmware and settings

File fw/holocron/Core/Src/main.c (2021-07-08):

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

/* Includes ------------------------------------------------------------------*/
#include "main.h"

/* USER CODE BEGIN Includes */
#include "hardware.h"
//#include "hardware.c"
/* USER CODE END Includes */

/* USER CODE BEGIN PD */
#define LOGLEN 500  // umber of data points
/* USER CODE END PD */

ADC_HandleTypeDef hadc;

I2C_HandleTypeDef hi2c1;

TIM_HandleTypeDef htim2;
TIM_HandleTypeDef htim6;
TIM_HandleTypeDef htim21;
TIM_HandleTypeDef htim22;

/* USER CODE BEGIN PV */
SABER_ExecState SaberState = SABER_OFF;

// Communication
HAL_StatusTypeDef rethal = HAL_OK;

// Timing Globals
uint32_t ticksPerSec = 1000;  // for timing: stm32l0xx_hal.h, period2ticks
uint32_t lastTick_DEBOUNCE = 0;
uint32_t lastTick_MTR = 0;
uint32_t ticksDEBOUNCE;
uint32_t ticksMTR;

// Debugging Globals
volatile uint16_t imtr;
volatile const int16_t * encTicks;
int16_t tgt = 20000;
int16_t err = 0;
volatile float u;
float ulog[LOGLEN];
int16_t errlog[LOGLEN];
uint16_t ilog[LOGLEN];
uint16_t logndx = 0;

/* USER CODE END PV */

void SystemClock_Config(void);
static void MX_GPIO_Init(void);
static void MX_I2C1_Init(void);
static void MX_TIM2_Init(void);
static void MX_TIM21_Init(void);
static void MX_TIM22_Init(void);
static void MX_ADC_Init(void);
static void MX_TIM6_Init(void);
/* USER CODE BEGIN PFP */
static inline void nextState_USER(void);
static inline uint32_t Period2Ticks(float);
static inline uint16_t accVal(uint8_t const * const);
static inline float ADC_GetMaxVal(void);
/* USER CODE END PFP */

/**
  * @brief  The application entry point.
  * @retval int
  */
int main(void)
{
  /* USER CODE BEGIN 1 */
  __disable_irq();  // wait for setup

  // static locals
//  static const uint8_t accRaw[10] = {0,0,0,0,0,0,0,0,0,0};  // TODO: why 10, not 8?
//  static const uint8_t accTxPacket[1] = {ACC_X_MSB_ADDR};

  // dynamic locals
//  uint16_t xacc,yacc,zacc;
//  uint16_t imtrs[3] = {0,0,0};  // TODO: programmatically setup lpf buffer
  /* USER CODE END 1 */

  /* MCU Configuration--------------------------------------------------------*/

  /* Reset of all peripherals, Initializes the Flash interface and the Systick. */
  HAL_Init();

  /* Configure the system clock */
  SystemClock_Config();

  /* USER CODE BEGIN SysInit */
  HAL_SetTickFreq(HAL_TICK_FREQ_1KHZ);
  ticksMTR = Period2Ticks(T_MTR);
  ticksDEBOUNCE = Period2Ticks(T_DEBOUNCE);
  /* USER CODE END SysInit */

  /* Initialize all configured peripherals */
  MX_GPIO_Init();
  MX_I2C1_Init();
  MX_TIM2_Init();
  MX_TIM21_Init();
  MX_TIM22_Init();
  MX_ADC_Init();
  MX_TIM6_Init();
  /* USER CODE BEGIN 2 */
  // enforce off
  MtrBrakeLo();
  HAL_GPIO_WritePin(SIG_SOL_GPIO_Port,SIG_SOL_Pin,0);
  HAL_GPIO_WritePin(SIG_LED_GPIO_Port,SIG_LED_Pin,0);

  // heartbeat
  htim6.Instance->ARR = (uint32_t) 32 * T_HBEAT;  // 2.097MHz / (65535+1) / 32 = 1Hz
  HAL_TIM_Base_Start_IT(&htim6);

  // encoder
  HAL_TIM_Encoder_Start(&htim22, TIM_CHANNEL_ALL);
  encTicks = &(htim22.Instance->CNT);  // signed encoder count

  // pwm
  htim2.Instance->CCR1 = 0;  // 0% duty cycle
  HAL_TIM_PWM_Start(&htim2, TIM_CHANNEL_1);

  /* USER CODE END 2 */

  /* Infinite loop */
  /* USER CODE BEGIN WHILE */
  __enable_irq();
  while (1) {
//    if (uwTick - lastTick_MTR > ticksMTR) {
//      // TODO: read motor current
//      err = *encTicks - tgt;
//      if (logndx < LOGLEN) {
//        ulog[logndx] = u;
//        errlog[logndx] = err;
//        logndx++;
//      }
//      CtlLaw(err);
//      SetMtrPWM(u);
//      lastTick_MTR = uwTick;
//    }
    for (int i=0;i<10;i++) {
      SetSpkrFreq(i*2000);
      HAL_Delay(1000);
    }
    // State Machine
//    switch (SaberState) {
//      case SABER_OFF:
//        break;
//      case SABER_EXTEND:
//        if ( !checkExtend() ) {  // TODO: actual control loop
//          MtrCtl(u);
//        }
//        break;
//      case SABER_RETRACT:
//        if ( !checkRetract() ) {  // TODO: actual control loop
//        }
//        break;
//      case SABER_ON:
//        // TODO: saber noises
//        // TODO: blinky lights
//        HAL_GPIO_WritePin(SIG_LED_GPIO_Port, SIG_LED_Pin, GPIO_PIN_RESET);
//        break;
//      default:
//        Error_Handler();
//        break;
//    }
  }
    /* USER CODE END WHILE */

}

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
/* USER CODE BEGIN 4 */

/**
  * @brief  Heartbeat timer interrupt implementation
  * @param  htim TIM handle
  * @retval None
  */
__weak void HAL_TIM_PeriodElapsedCallback(TIM_HandleTypeDef *htim)
{
  __disable_irq();
  if (htim == &htim6) {  // only use htim6
    HAL_GPIO_TogglePin(LED_HBEAT_GPIO_Port, LED_HBEAT_Pin);
  }
  __enable_irq();
}


/*****************************************************************************
 * STATE BEHAVIOR
 ****************************************************************************/
/**
  * @brief  EXTI line detection callbacks.
  * @param  GPIO_Pin Specifies the pins connected to the EXTI line.
  * @retval None
  */
void HAL_GPIO_EXTI_Callback(uint16_t GPIO_Pin)
{
  __disable_irq();
  switch (GPIO_Pin) {
    case BTN_Pin:
      if (uwTick-lastTick_DEBOUNCE > ticksDEBOUNCE) {
        nextState_USER();
        lastTick_DEBOUNCE = uwTick;
      }
      break;
  }
  __enable_irq();
}

/** @defgroup Exec_Saber_State  Saber state subroutines.
  * @{
  */

/**
  * @brief  Advance saber state from user input.
  * @retval None
  */
static inline void nextState_USER(void)
{
  switch (SaberState) {
    case SABER_LOW_BATT:
      break;
    case SABER_OFF:
      SaberState = SABER_EXTEND;
      break;
    case SABER_EXTEND:
      SaberState = SABER_RETRACT;
      break;
    case SABER_ON:
      SaberState = SABER_RETRACT;
      break;
    case SABER_RETRACT:  // TODO: it won't just jump like this, will it?
      SaberState = SABER_EXTEND;
      break;
    default:
      Error_Handler();
      break;
  }
}

/*****************************************************************************
 * Config Functions
 ****************************************************************************/
/**
 * @brief Convert Period to Number of System Ticks
 * @param T execution period in seconds
 * @retval Execution period in system ticks
 */
static inline uint32_t Period2Ticks(float T)
{
	return (uint32_t)(T * ticksPerSec);
}


/**
 * @brief Get ADC Resolution from Config Struct
 * @note Run AFTER system configuration
 * @retval Maximum ADC value
 */
static inline float ADC_GetMaxVal(void)
{
  uint8_t bs = 0;  // bitshift for adc resolution
  switch (hadc.Init.Resolution) {
    case ADC_RESOLUTION_12B:
      bs = 12;
      break;
    case ADC_RESOLUTION_10B:
      bs = 10;
      break;
    case ADC_RESOLUTION_8B:
      bs = 8;
      break;
    case ADC_RESOLUTION_6B:
      bs = 6;
      break;
    default:
      Error_Handler();
  }
  return (float)(1U<<bs) - 1;
}

/**
 * @brief Convert I2C Data to Accelerometer Reading
 * @note See hardware.h accelerometer section for details.
 * @param d length-2 uint8 accelerometer data
 * @retval Acceleration in counts
 */
static inline uint16_t accVal(uint8_t const * const d)
{
  return ((*d)<<ACC_BIT0_SHIFT) + (*(d+1)<<ACC_BIT1_SHIFT);
}

/* USER CODE END 4 */
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


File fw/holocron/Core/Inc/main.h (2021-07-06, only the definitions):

#define T_HBEAT (float) 0.5         // LED Heartbeat Period
#define T_ACC (float) 0.1         // Accelerometer Update Period
#define T_BATT (float) 600        // Voltage Update Period
#define T_EXTEND (float) 0.1      // Saber Extension Time
#define T_RETRACT (float) 0.3     // Saber Retraction Time
#define T_MTR (float) 0.01      // motor polling time
#define PWM_SPKR_Pin GPIO_PIN_2
#define PWM_SPKR_GPIO_Port GPIOA
#define INA_Pin GPIO_PIN_3
#define INA_GPIO_Port GPIOA
#define ADC_imtr_Pin GPIO_PIN_4
#define ADC_imtr_GPIO_Port GPIOA
#define PWM_MTR_Pin GPIO_PIN_5
#define PWM_MTR_GPIO_Port GPIOA
#define INB_Pin GPIO_PIN_6
#define INB_GPIO_Port GPIOA
#define LED_HBEAT_Pin GPIO_PIN_7
#define LED_HBEAT_GPIO_Port GPIOA
#define SIG_SOL_Pin GPIO_PIN_0
#define SIG_SOL_GPIO_Port GPIOB
#define SIG_LED_Pin GPIO_PIN_1
#define SIG_LED_GPIO_Port GPIOB
#define BTN_Pin GPIO_PIN_9
#define BTN_GPIO_Port GPIOA
#define BTN_EXTI_IRQn EXTI4_15_IRQn
#define ENC_A_Pin GPIO_PIN_4
#define ENC_A_GPIO_Port GPIOB
#define ENC_B_Pin GPIO_PIN_5
#define ENC_B_GPIO_Port GPIOB

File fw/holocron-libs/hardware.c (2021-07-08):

/**
  ******************************************************************************
  * @file    hardware.c
  * @author  Marion Anderson
  * @brief   Hardware Configuration C File
  ******************************************************************************
  */
#include "main.h"
#include "hardware.h"
#include "math.h"

extern TIM_HandleTypeDef htim2;
extern TIM_HandleTypeDef htim21;
extern TIM_HandleTypeDef htim22;
extern const int16_t tgt;
extern const int16_t * const encTicks;
extern float u;

/*****************************************************************************
 * Motor Actuation - Direction & PWM
 ****************************************************************************/

/**
 * @brief Set hbridge direction pins to Clockwise Rotation.
 */
void MtrCW(void)
{
  HAL_GPIO_WritePin(INA_GPIO_Port, INA_Pin, GPIO_PIN_SET);
  HAL_GPIO_WritePin(INB_GPIO_Port, INB_Pin, GPIO_PIN_RESET);
}

/**
 * @brief Set hbridge direction pins to Counter-Clockwise Rotation.
 */
void MtrCCW(void)
{
  HAL_GPIO_WritePin(INA_GPIO_Port, INA_Pin, GPIO_PIN_RESET);
  HAL_GPIO_WritePin(INB_GPIO_Port, INB_Pin, GPIO_PIN_SET);
}

/**
 * @brief Set hbridge direction pins to hard-stop motor at VBATT.
 */
void MtrBrakeHi(void)
{
  HAL_GPIO_WritePin(INA_GPIO_Port, INA_Pin, GPIO_PIN_SET);
  HAL_GPIO_WritePin(INB_GPIO_Port, INB_Pin, GPIO_PIN_SET);
}

/**
 * @brief Set hbridge direction pins to hard-stop motor at GND.
 */
void MtrBrakeLo(void)
{
  HAL_GPIO_WritePin(INA_GPIO_Port, INA_Pin, GPIO_PIN_RESET);
  HAL_GPIO_WritePin(INB_GPIO_Port, INB_Pin, GPIO_PIN_RESET);
}

/**
 * @brief Set all hbridge GPIO according to motor input voltage u
 * @param (global) u Motor input voltage
 */
void SetMtrPWM(float u)
{
  if (u<0) {
    MtrCCW();
  } else if (u>0) {
    MtrCW();
  }
  u = (u>0) ? u : -u;
  htim2.Instance->CCR1 = htim2.Instance->ARR * u / MV;
}


/**
 * Set Speaker PWM Frequency
 * @param freq Frequency in Hz (up to 20,000).
 */
const float freq2arr = 3.3; // 0<->0, 20,000 <-> 2^16-1
void SetSpkrFreq(uint16_t freq)
{
  htim21.Instance->ARR = (uint16_t) freq * freq2arr;
  htim21.Instance->CCR1 = htim21.Instance->ARR >> 2;
}


/*****************************************************************************
 * Motor Control
 ****************************************************************************/

/**
 * @brief Motor control law
 * @param err System error
 * @retval (global update) Output voltage
 * TODO: integrator windup prevention
 */

void CtlLaw(int16_t err)
{
  static int32_t erri = 0;
  static uint32_t errd = 0;
  static float errbuf[ND] = {0};
  static uint32_t i = 0;  // iteration var
  // derivative term
  errd = 0;
  for (i=1;i<ND;i++) {
    errbuf[i-1] = errbuf[i];
    errd += errbuf[i];
  }
  errbuf[ND-1] = err;
  errd += err;
  // integral term
  if (fabs(u) < MV) {  // anti-windup
    erri += err;
  }
  // computation
  u = KP*err + KI*erri*T_MTR + KD*errd/T_MTR/3;
}

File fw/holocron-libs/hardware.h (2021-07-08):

/**
  ******************************************************************************
  * @file    hardware.h
  * @author  Marion Anderson
  * @brief   Hardware Configuration Header File
  ******************************************************************************
  */

#ifndef INC_HARDWARE_H
#define INC_HARDWARE_H

#include "stm32l0xx_hal_i2c.h"
#include "stm32l0xx_hal_gpio.h"
#include "stm32l0xx_hal_tim.h"
#include "math.h"
#include "main.h"

/*****************************************************************************
 * Accelerometer IO - MMA8452 Addresses & Helper Functions
 ****************************************************************************/
extern I2C_HandleTypeDef hi2c1;
#define ACC_I2C hi2c1
#define ACC_ADDR 0x1DU
// reading
#define ACC_X_MSB_ADDR 0x01U
// control registers
#define ACC_CTRL_REG1 0x2AU
#define ACC_CTRL_REG2 0x2BU
#define ACC_CTRL_REG3 0x2CU
#define ACC_CTRL_REG4 0x2DU
#define ACC_CTRL_REG5 0x2EU
// data
#define COUNTS_PER_G 1024U
#define ACC_BIT0_SHIFT 4U
#define ACC_BIT1_SHIFT 0U
/*****************************************************************************
 * Button IO
 ****************************************************************************/
#define T_DEBOUNCE (float) 0.2  // Debounce time for button (ms)
/*****************************************************************************
 * ADCs
 ****************************************************************************/
#define VREF 3.3
static const float VOLTS_PER_COUNT = ((float) VREF) /  4096;  // TODO: get res dynamic
float counts2volt(uint32_t);
/*****************************************************************************
 * MOTOR
 ****************************************************************************/
// sensing
#define MRSENSE 1500U  // Ohms
#define MIGAIN 11000U  // VNHD7008AY datasheet p15
static const uint32_t MTR_I_MULT = MRSENSE*MIGAIN;

// control gains
#define K0 ((float) 1)
#define KP ((float) 0.5)
#define KI ((float) 0)
#define KD ((float) 0)
#define ND 3  // derivative averager length
static const float DERVQUOTIENT = ND * T_MTR;

// motor params (metric!!)
#define ML 100 // uH
#define MR 2   // Ohms
#define MV 12  // Input Voltage
#define MJ 1   // Inertia
#define MK 1   // Torque Constant
#define MD 1   // Friction Constant

// functions
void MtrCW(void);
void MtrCCW(void);
void MtrBrakeHi(void);
void MtrBrakeLo(void);
void MtrCtl(void);  // TODO: set channel compare preload?
void CtlLaw(int16_t);
uint8_t checkExtend(void);
uint8_t checkRetract(void);

/*****************************************************************************
 * Speaker
 ****************************************************************************/
void SetSpkrFreq(uint16_t);

#endif /* INC_HARDWARE_H_ */

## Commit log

2021-04-07 Switched to STM32G031F8P6 chip for more flash memory
2021-04-07 exploring spi hbridge options
2021-04-07 testing switch to STM32L031F4
2021-04-07 Use CubeIDE-1.3.0. Working blinky/accelermeter I2C.
2021-04-07 initial hbridge/fet sims
2021-04-07 starting gpio interrupt configuration
2021-04-07 motor parameter spreadsheet
    [motor_params.ods]
2021-04-07 GPIO interrupts and better state machine. Cleaner code
2021-04-24 init PCB schematic - hierarchy,mcu pinout,some chip selection,basic circuit implementation
    [actuators.sch, micro.sch, power.sch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]
2021-04-24 sized battery protections FETs,zeners,resistors
    [actuators.sch, micro.sch, power.sch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]
2021-04-24 forgot to push pcb .lib file :(
2021-04-24 saving partially complete hbridge symbol just in case
    [actuators.sch]
2021-04-24 working on actuators. some schematic cleanup
    [actuators.sch, micro.sch, power.sch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]
2021-04-24 redid sch to use hbridge IC significant built-in functionality
    [actuators.sch, hbridge.sch, micro.sch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]
2021-04-24 update rpp circuit description in readme
2021-04-25 major schematic cleanup. sized diodes.
    [actuators.sch, hbridge.sch, micro.sch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]
2021-04-25 minor schematic formatting
    [saber.sch]
2021-05-02 ERC cleanup; sized capacitors and inductors
    [actuators.sch, hbridge.sch, micro.sch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]
2021-05-02 found mosfet with denser footprint. search now renewed
    [actuators.sch, hbridge.sch, micro.sch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]
2021-05-02 ditched battery sensing & chose basic footprints
    [actuators.sch, hbridge.sch, micro.sch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]
2021-05-02 repicked mcu pins for layout
    [actuators.sch, hbridge.sch, micro.sch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]
2021-05-02 better hierarchy; more footprint assignment
    [D_PowerDI5-AAK.step, D_PowerDI5-KKA.step, PDS1040L-13.step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]
2021-05-06 started motor control code. needs serious readability architecture
2021-05-06 working on motor characterization project, updated readme
2021-05-06 working chan2 pwm -- pulse_chan/counter_period = duty cycle
2021-05-07 working motor duty cycle & dir control
2021-05-07 pwm sweep demo
2021-05-08 working encoder
2021-05-08 avoid encoder double/quadruple counting by bitshifting - (TIM22->CNT)>>1
    [main.c]
2021-05-08 signed encoder working (use int16)
2021-05-08 started motor control subproj
2021-05-09 Ready-for-first-layout schematic.
    TODOs
    - correct power fet footprints
    - pick similar ST micro (need more flash for floats)
    [STL120N4F6AG.step, STL76DN4LF7AG.step, acc.sch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]
2021-05-09 building motor control testing
2021-05-09 accelerometer pinout correction
    [hbridge.sch]
2021-05-09 reselected diodes, split up connector TBs for layout purposes
    [acc.sch, actuators.sch, hbridge.sch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]
2021-05-13 started cad for winding winch
    [winch.FCStd]
2021-05-13 rechose diodes for density
    [acc.sch, actuators.sch, hbridge.sch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]
2021-05-14 pre-datasheet-review placement
    [acc.sch, actuators.sch, hbridge.sch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]
2021-05-14 4 layer board for density. Need to re-choose motor cap
    [hbridge.sch, saber.kicad_pcb]
2021-05-14 additional layout changes for density
    [saber.kicad_pcb]
2021-05-14 increased density by removing a mounting hole so large cap takes up that corner
    [hbridge.sch, micro.sch, saber.kicad_pcb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]
2021-05-16 base saber stls from thingiverse (see credits.txt)
    [EP6_Luke_Grip_Solid.STL, EP6_Luke_Midsection_Solid.STL, EP6_Luke_Pommel_Solid.STL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]
2021-05-21 editing layout for density
    [acc.sch, actuators.sch, hbridge.sch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]
2021-05-21 more shrinking layout
    [saber.kicad_pcb]
2021-05-22 Maximum density placement. Next: Tidy for routing + minor footprint corrections
    [saber.kicad_pcb]
2021-05-26 correct weird pad for STL76DN4LF7AG
    [micro.sch, saber.kicad_pcb]
2021-05-26 STL76DN4LF7AG footprint updated
2021-05-26 pre-netlist reload commit. st transistor updated symbols + footprints
    [saber.kicad_pcb]
2021-05-27 power+hbridge routing round 1. fixed a transistor orientation error.
    [hbridge.sch, micro.sch, saber.kicad_pcb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]
2021-05-29 starting signal routing
    [hbridge.sch, power.sch, saber.kicad_pcb]
2021-05-29 noted more pin-specific capacitor connections
    [acc.sch, hbridge.sch, micro.sch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]
2021-05-29 removed all testpoints for density reasons. may add SDA/SCL test points back in
    [saber.kicad_pcb, saber.sch]
2021-05-29 Initial routing complete
    [hbridge.sch, micro.sch, saber.kicad_pcb]
2021-05-29 renamed PCB project to KyberBoard
    [D_PowerDI5-AAK.step, D_PowerDI5-KKA.step, KyberBoard.kicad_pcb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]
2021-06-01 finally pushed project symbol lib file
    [KyberBoard.sch, acc.sch, actuators.sch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]
2021-06-04 working adc code and minor circuit correction
    [KyberBoard.kicad_pcb, KyberBoard.sch, acc.sch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]
2021-06-06 prepping board for fab -- DRC,easter eggs,silkscreen
    [KyberBoard.kicad_pcb, _saved_acc.sch, _saved_hbridge.sch]
2021-06-06 corrected FET footprint (missing mask on pad) and more easter eggs
    [KyberBoard.kicad_pcb, _saved_acc.sch, _saved_hbridge.sch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]
2021-06-07 cleaned silkscreen and checked design rules. almost ready for fab
    [KyberBoard.kicad_pcb, KyberBoard.sch]
2021-06-07 board ready to send out to fab
    [KyberBoard.kicad_pcb]
2021-06-07 found major ACC footprint error. Corrected + redid local placement + routing
    [KyberBoard-B.Cu.gbr, KyberBoard-B.Mask.gbr, KyberBoard-B.SilkS.gbr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]
2021-06-07 gerber files updated per JLCPCB Kicad5 tutorial
    [KyberBoard-B.Cu.gbl, KyberBoard-B.Mask.gbs, KyberBoard-B.Paste.gbp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]
2021-06-08 Completed BOM; board sent to fab house
    [KyberBoard-BOM.xlsx, KyberBoard.kicad_pcb, acc.sch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]
2021-06-08 drawing cleanup & pdfs
    [KyberBoard.kicad_pcb, KyberBoard.sch, acc.sch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]
2021-07-04 PCB Bring-Up Day 1 Revisions
    - Touched up undervoltage cutout circuit
    - Stronger PMOS pull-up (10kOhms was not working; replaced with 1k & called good)
    - 10kOhms LED current-limiting resistor
    - Corrected minor schematic discrepancies from PCB
    - undervoltage indicator circuit was correct in PCB but not schematic
    - Changed mounting holes from M3 to M2.5 (Raspberry Pi size)
    - Found that identifiers can be made invisible
    - now mounting holes have identifiers that do not appear on silkscreen
    - similar logic for LED indicators and jumpers
    [KyberBoard.kicad_pcb, KyberBoard.sch, acc.sch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]
2021-07-05 timer-interrupt heartbeat. working on button + motor control
2021-07-06 working encoder code in holocron
2021-08-01 starting saber chassis testbed
    [test_rig.FCStd]
2021-08-28 started work on winch system
    [MTRBRACKTEST.FCStd, assembly.FCStd, motor-bracket.FCStd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]
2021-08-31 reworking pcb to be compatible with LED strip
    [KyberBoard.kicad_pcb, KyberBoard.sch, acc.sch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]

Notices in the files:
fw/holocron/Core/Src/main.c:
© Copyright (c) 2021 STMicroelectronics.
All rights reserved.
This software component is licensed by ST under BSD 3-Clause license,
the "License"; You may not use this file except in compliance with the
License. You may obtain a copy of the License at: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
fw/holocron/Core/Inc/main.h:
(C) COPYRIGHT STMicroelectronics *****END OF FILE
